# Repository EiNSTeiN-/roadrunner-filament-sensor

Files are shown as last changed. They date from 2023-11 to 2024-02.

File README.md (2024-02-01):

# Roadrunner: a high resolution filament motion sensor

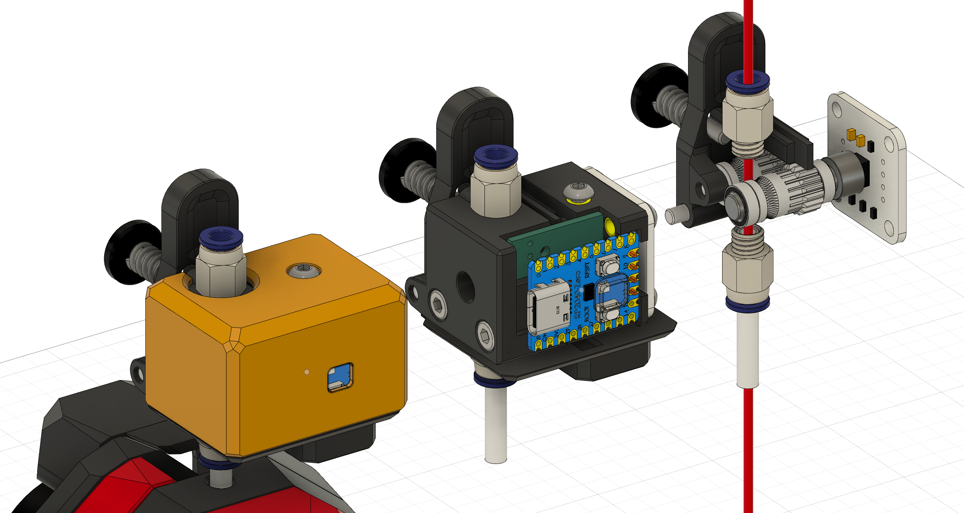
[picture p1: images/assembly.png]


### Features

* **High resolution** sub-millimeter motion detection
* **Low cost** at approx. ~12$ USD for parts on Aliexpress
* **Detect direction** (extruding or reversing) unlike pulse-based motion sensors
* Detect changes of **0.7 degree** or 0.04mm based on a 24mm rotation distance
* **Neopixel status indicator** for filament removed, filament inserted, filament moving
* **Small and light** at half the size of some commercial products
* **Helps determine runout reason** between filament runout, filament jams, or partial under-extrusion
* **2-wire communication** with mcu, over UART or I2C (suits most boards)
* **Calibrates max flow** with helpful gcode command.

Most 3D printer motion sensors are bulky, slow to trigger, prone to false positives, and have a high detection distance meaning a large amount material is extruded before actually detecting a runout, leading to poor layer adhesion and failed prints after a runout.

The Roadrunner motion sensor is based on a magnetic rotary encoder which can detect sub-millimeter movement in the filament for accurate extrusion length measurement, in addition to an IR sensor which can instantly detect filament runout. With the combination of both sensors and a dedicated RP2040-Zero board for collecting data, the Roadrunner can detect which type of issue is affecting a print, between simply reaching the end of a spool, the filament no longer moving, or the filament moving but at a lower than expected rate of extrusion.

By leveraging the higher precision of the sensor, it's possible to determine the length, speed and volumetric flow that are expected and compare them to the actual measured values in real time which gives us a reasonable approximation of _how much_ the filament is being under-extruded by. A simple to use `CALIBRATE_MAX_FLOW` command is provided to perform free-air extrusion tests and automatically benchmark the maximum volumetric flow of any temperature/nozzle/material combination.

### Build guide

This is an open-source project, so you can build your own!

See the [bill of material](manual/BOM.md) and the [assembly manual](manual/ASSEMBLY.md).

### Klipper installation

Clone the repository and create a symlink to the sensor code:

```
cd ~
git clone --depth 1 --single-branch https://github.com/EiNSTeiN-/roadrunner-filament-sensor.git
~/roadrunner-filament-sensor/install.sh
```

Restart klipper for the new sensor type to be recognized:
```
sudo service klipper restart
```

To get automatic updates within moonraker, add the following block at the end of `moonraker.conf`:
```ini
[update_manager roadrunner-filament-sensor]
type: git_repo
path: ~/roadrunner-filament-sensor
origin: https://github.com/EiNSTeiN-/roadrunner-filament-sensor.git
install_script: install.sh
primary_branch: main
managed_services: klipper
```

### Configuration

Add the following configuration to your `printer.cfg`:

```
[high_resolution_filament_sensor roadrunner]
extruder: extruder
#  The extruder to which this sensor is attached
uart_rx_pin: P0.0
uart_tx_pin: P0.1
#  TX and RX pins for UART communication, leave out if i2c or USB serial is used (see below).
#i2c_address: 64
#  The address of the sensor on the I2C bus, the default is 64 (0x40). Only
#  change this if you attach more than one sensor on the same I2C bus.
#i2c_mcu: mcu
#  The mcu on which the sensor is connected.
#i2c_bus: i2c1
#  The I2C bus to which the sensor is connected on the mcu.
#serial: /dev/serial/by-id/usb-Raspberry_Pi_Pico_E66130100F655734-if00
#  The serial port over which the sensor is connected. Find with `ls -alh /dev/serial/by-id`.
pause_on_runout: False
#  Whether or not to pause the print automatically when a runout
#  condition is triggered.
runout_gcode: RESPOND TYPE=command MSG='Filament runout detected'
#  The gcode to execute when a runout condition is detected.
invert_direction: False
# If the measured distance/speed values are negative, change this to True.
rotation_distance: 23.4
# The length of filament which corresponds to a full 360 degree rotation
# of the magnet over the rotary encoder. A good starting point is the
# circumference of the BMG gears in the sensor.
underextrusion_max_rate: 0.5
# What rate of underextrusion can be tolerated, as a value between 0.0 and 1.0.
# The rate is calculated by comparing the extruder position to the measured
# filament length over a certain period. A rate of 0.0 means the measured
# filament motion matches the expected extrusion distance over the period.
# A rate of 1.0 means no filament motion was detected at all when some motion
# was expected for the extruder.
underextrusion_period: 5
# How long should the underextrusion rate stay above the max rate before
# a runout is triggered.
hysteresis_bits: 3
# How many bits to ignore from the magnetic rotary encoder's angle data.
# This setting determines the minimum detectable change in position
# for the sensor. Configuring this too low can result in flapping between
# two adjacent positions even when the filament is not moving.
```

Two virtual pins are created for each sensor, which can be used to configure a [`filament_motion_sensor`](https://www.klipper3d.org/Config_Reference.html#filament_motion_sensor) or a [`filament_switch_sensor`](https://www.klipper3d.org/Config_Reference.html#filament_switch_sensor). This is mainly for convenience of use with user interfaces like mainsail/fluid. The virtual motion sensor will be triggered as soon as the sensor moves by the minimum detectable distance. The switch sensor will trigger when the IR sensor detects the filament is present. Both objects will work independently of the runout detection algorithm implemented in `high_resolution_filament_sensor` which considers additional factors such as underextrusion.

An example configuration would look like:

```
[filament_motion_sensor roadrunner_motion]
detection_length: 2
extruder: extruder
switch_pin: virtual_motion_sensor:roadrunner
pause_on_runout: False
runout_gcode: RESPOND TYPE=command MSG='Filament motion sensor detected a runout'
event_delay: 0.1

[filament_switch_sensor roadrunner_switch]
switch_pin: virtual_switch_sensor:roadrunner
pause_on_runout: False
runout_gcode: RESPOND TYPE=command MSG='Filament switch sensor detected filament is no longer present'
event_delay: 0.1
```

### Usage

##### Calibration cheat sheet

Here's an example of a complete calibration workflow:

```
# Disable a few things for these tests
SET_PRESSURE_ADVANCE EXTRUDER=extruder ADVANCE=0
SET_Z_THERMAL_ADJUST TEMP_COEFF=0 ENABLE=0

# Optionally home the printer and move to a safe Z
G32
G0 Z100

# Check your sensor info
QUERY_FILAMENT_SENSOR SENSOR=roadrunner

# Find rotation_distance value, don't forget to save it in the sensor config & restart.
CALIBRATE_FILAMENT_SENSOR_ROTATION_DISTANCE SENSOR=roadrunner TEMP=250 LENGTH=30 SPEED=30 COUNT=10

# Find max flow for this extruder, save the graph of collected data for future reference (THIS WILL TAKE A WHILE)
CALIBRATE_MAX_FLOW SENSOR=roadrunner TEMP=250 START=1 STOP=40 SAVE_GRAPH=1

# Measure a G1 command at a high speed (e.g. 11.5mm/s = 690mm/m).
# Use a value that will produce a flow in the non-linear part of the curve in the previous graph.
FILAMENT_SENSOR_MEASURE SENSOR=roadrunner TEMP=250 SPEED=690 LENGTH=100 SAVE_GRAPH=1

# Enable nonlinear extrusion with coefficients suggested by `CALIBRATE_MAX_FLOW`
ENABLE_NONLINEAR_EXTRUSION SENSOR=roadrunner ENABLE=1 COEFFICIENTS=-0.1106867,1.1197162,-0.0347608,0.0028625

# Take same measurement again, the measured length and speed should show little deviation.
FILAMENT_SENSOR_MEASURE SENSOR=roadrunner TEMP=250 SPEED=690 LENGTH=100 SAVE_GRAPH=1

# Now check the result of the extrusion compensation by generating a new graph (THIS WILL TAKE A WHILE)
CALIBRATE_MAX_FLOW SENSOR=roadrunner TEMP=250 START=1 STOP=40 STEP=2 COUNT=2 SAVE_GRAPH=1
```

##### Calibrate the sensor's rotation distance:

The first thing to do is to calibrate the `rotation_distance` for the sensor itself. This is done
with `CALIBRATE_FILAMENT_SENSOR_ROTATION_DISTANCE`:

```
CALIBRATE_FILAMENT_SENSOR_ROTATION_DISTANCE SENSOR=roadrunner TEMP=250 LENGTH=30 SPEED=60 COUNT=10
```

* `TEMP`: The temperature to heat up the extruder heater at. Default is 200.
* `LENGTH`: The length of filament to retract. Default is 25.
* `SPEED`: The extrusion speed, in rotation per minute (e.g. 300 means 5mm/s). Default is 30 (0.50mm/s).
* `COUNT`: How many times to perform the test. Default is 10.

This macro will heat up the extruder heater to the specified temperature, retract the filament multiple times,
and calculate some stats. The measurement is done while retracting the filament to avoid introducing an error
due to the back-pressure in the nozzle. Make sure a length of filament at least `LENGTH` mm long can
be retracted while still being gripped by the extruder gears. For best results, perform this test at low
speed over a distance long enough for the sensor's gears can do one full rotation.

After the distance measurements are taken, they are sorted by frequency and the measurement with the highest frequency is used to calculate a new `rotation_distance`. For example, if 8/10 measurements read 25.62mm when 25mm was expected, the `rotation_distance`
was too high and a new value is automatically suggested. After saving the new `rotation_distance` in your sensor configuration, repeating the test with the same macro parameters should measure the correct distance. The deviation between measurements is reported relative to the minimum detectable change in position, a small deviation indicates repeatable measurements. While the sensor is
high precision, its accuracy and repeatability over multiple readings can be affected by real world factors such as
springiness in the PTFE tube, the attachement of the sensor to the body of the extruder, etc.

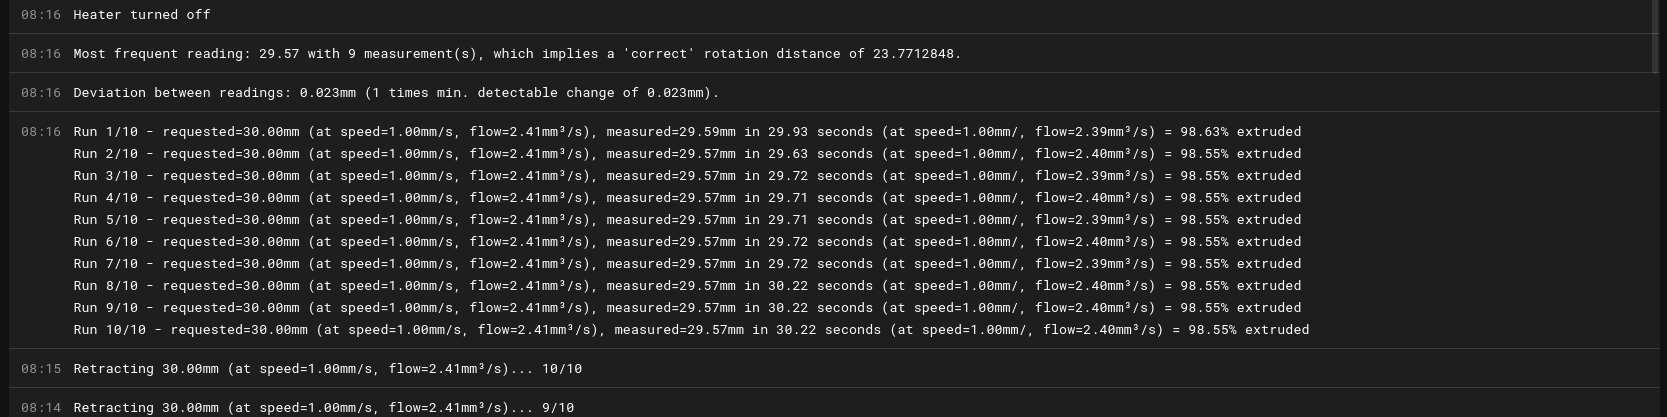
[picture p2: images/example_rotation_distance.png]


##### Measure a G1 command

Extrude some filament using a G1 command, and print the result as measured by the sensor.

```
FILAMENT_SENSOR_MEASURE SENSOR=roadrunner TEMP=250 LENGTH=10 SPEED=120 COUNT=1
```

* `TEMP`: The temperature to heat up the extruder heater at. Default is 200.
* `LENGTH`: The length of filament to retract. Default is 10.
* `SPEED`: The extrusion speed, in rotation per minute (e.g. 300 means 5mm/s). Default is 120 (2mm/s).
* `COUNT`: How many times to perform the test. Default is 1.
* With the `SAVE_GRAPH=1` parameter, a graph of all measurements is saved to klipper's current working directory (usually `~/klipper/`).

The macro will run one or more G1 command until the desired length of filament is extruded. The macro will print stats for each move, as measured by the sensor.

Optionally if a graph is saved, the output will look like this:

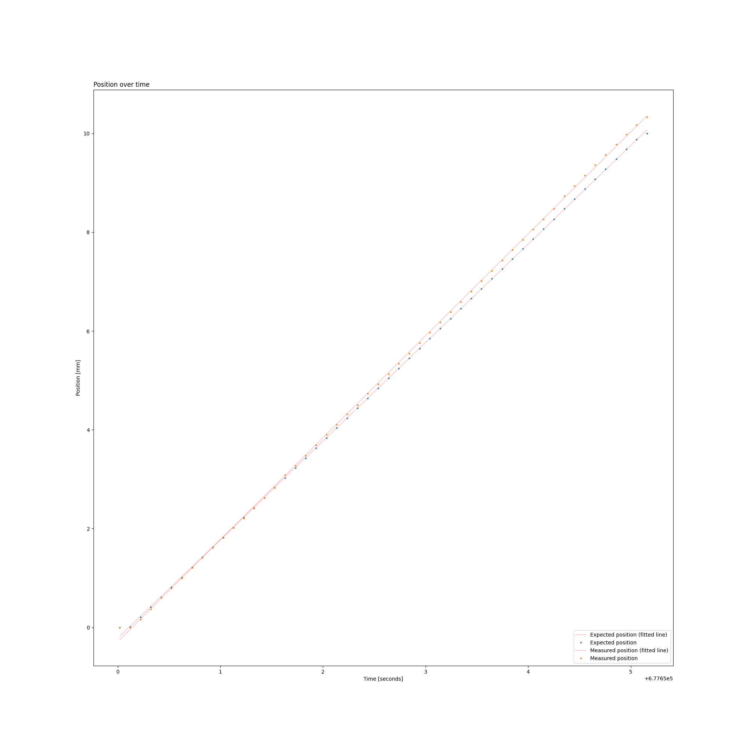
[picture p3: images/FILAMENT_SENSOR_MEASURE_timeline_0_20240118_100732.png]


##### Max flow calibration

The goal of this macro is to help determine the maximum volumetric flow for a given combination of filament, nozzle and temperature. Before starting, make sure your extruder's `filament_diameter` is correct, as well as the filament sensor's `rotation_distance`. For best results, the `STOP` value should be above or near the top of your extruder's expected maximum volumetric flow rate.

```
CALIBRATE_MAX_FLOW SENSOR=roadrunner TEMP=250 START=1 STOP=50 SAVE_GRAPH=1
```

* `TEMP`: The temperature to heat up the extruder heater at. Default is 200.
* `DURATION`: How long to extrude for during each test, used to determine the extrusion length (length = speed * duration). Default is 10 seconds.
* `START`: The minimum volumetric flow to test. Default is 5.
* `STOP`: The maximum volumetric flow to test. Default is 25.
* `STEP`: The amount by which to increment the volumetric flow between each test. Default is 1.
* `COUNT`: How many times to perform the test for each volumetric flow value. Default is 5.
* `MAX_SPEED_DEVIATION`: The percentage of deviation between the expected and the measured speed that will be considered acceptable. Used for recommending a maximum volumetric flow. Default is 0.05 (5%).
* With the `SAVE_GRAPH=1` parameter, a graph of all measurements is saved to klipper's current working directory (usually `~/klipper/`).

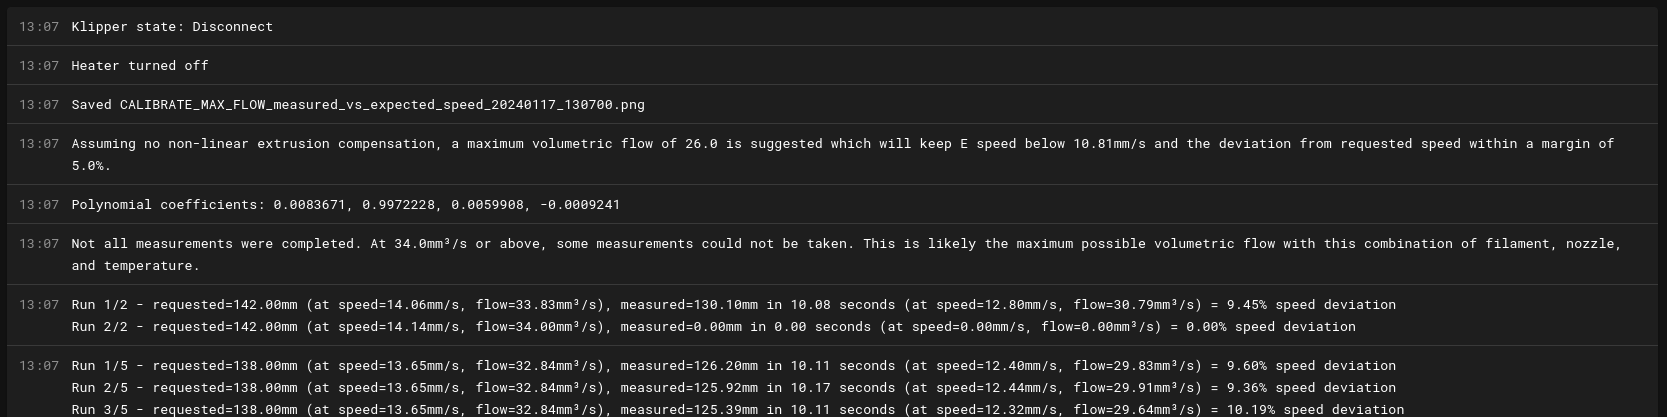
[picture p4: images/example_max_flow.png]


This macro will warn when a given volumetric flow was so high that not all measurements could be taken at this rate. This often corresponds to the physical limit of the extruder, where the back-pressure is so high that the extruder cannot keep up and eats into the filament.

After the measurements are taken, this macro will look for a range of speeds where the deviation between the expected and measured speeds is below `MAX_SPEED_DEVIATION` percent. At higher speeds, the back-pressure in the nozzle will cause under-extrusion, this can be identified visually in the data graph (use `SAVE_GRAPH=1`) as a part of the curve where the exected and measured speeds start deviating sharply. A polynomial curve is fitted to the relationship between the expected vs measured speeds, which can be used to compensate for the under-extrusion at higher speeds.

Optionally if a graph is saved, the output will look like this:

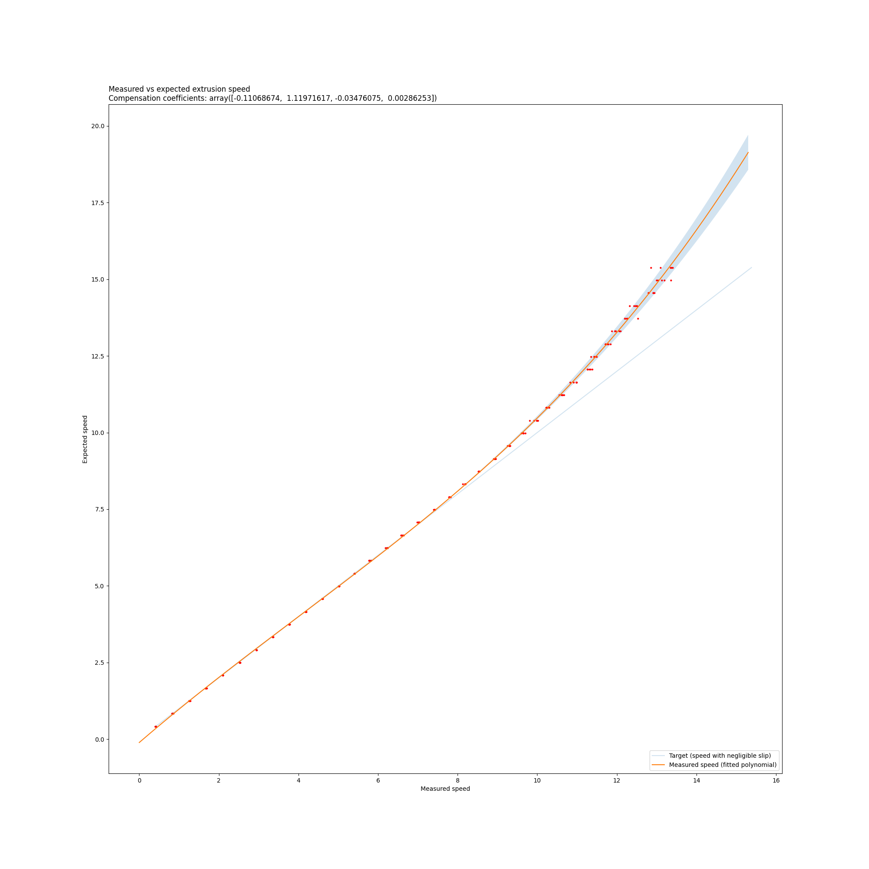
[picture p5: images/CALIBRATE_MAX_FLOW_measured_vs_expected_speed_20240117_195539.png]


##### Enable non-linear extrusion compensation (EXPERIMENTAL)

A `[non_linear_extrusion]` config section must be added for this command to work with a given extruder:
```
[non_linear_extrusion t0]
extruder: extruder
# Name of the extruder for which nonlinear extrusion compensation can optionally
# be enabled.
```

When non-linear extrusion compensation is enabled, the increase in pressure in the extruder will be compensated by increasing the requested speed of G1 commands. This applies to both extrude-only moves as well as regular printing moves. The compensation is only applied when using relative coordinates and only when a positive E distance is specified since retraction moves are not affected by pressure in the nozzle.

```
ENABLE_NONLINEAR_EXTRUSION EXTRUDER=extruder ENABLE=1 COEFFICIENTS=-0.1106867,1.1197162,-0.0347608,0.0028625
```

* `ENABLE`: 1 to enable, 0 to disable
* `COEFFICIENTS`: A list of comma-separated polynomial coefficients.

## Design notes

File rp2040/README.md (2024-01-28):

### Dependencies

```
sudo apt install cmake gcc-arm-none-eabi libnewlib-arm-none-eabi libstdc++-arm-none-eabi-newlib
```

### Configuring

Some neopixels have RGB color ordering while others have GRB. When the filament is inserted the LED should ligth green, if it is RED then you should use the GRB ordering. Uncomment the following line in `neopixel.h` and re-run `make` to build the firmware.

```
#define GRB_LED_ORDER 1
```

### Building

```
git clone https://github.com/EiNSTeiN-/roadrunner-filament-sensor.git
cd roadrunner-filament-sensor
git submodule update --init --recursive
cd rp2040
mkdir build
cd build
cmake ..
make
```

You'll find multiple `.uf2` files in the `roadrunner-filament-sensor/rp2040/build` directory. The name contains `uart`, `i2c` or `usbserial` for the communication mode between mcu and sensor, and `rgb` vs `grb` for the neopixel type.

### Flashing

1. Connect RP2040-Zero to computer via USB
2. Press `BOOT` and `RESET` at the same time
3. Release `RESET` and 1 second later release `BOOT`
4. A drive named `RPI-RP2` will appear
5. Copy newly built `.uf2` file to the drive to flash the new firmware.

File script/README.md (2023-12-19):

### Dependencies

This step is only needed once:

```
python3 -m venv ./venv
source ./venv/bin/activate
pip install -r requirements.txt
```

### Usage

Make sure the venv is activated before running the commands below:
```
source ./venv/bin/activate
```

See help for all command line options:

```
python3 main.py -h
```

##### Stream live data from printer

```
python3 main.py --http --live mainsailos.local
```

##### Save live data from printer to a file

```
python3 main.py --live mainsailos.local -f data.json
```

`--http` and `-f` can be combined to stream and save to a file at the same time.

##### Replay saved data from a file

```
python3 main.py --http --replay data.json
```

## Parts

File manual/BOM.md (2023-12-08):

# BOM

### Printed parts

Recommended settings:
* 0.2mm layer height
* 0.5mm (250%) layer width
* Cubic infill, 60%
* Supports enabled

| Part | Quantity | Notes |
|---|---|---|
| [a]_cover.stl | 1 | Print in accent color
| [c]_led_diffuser.stl | 1 | Print in clear material
| body_part_a.stl | 1 | Print in main color
| body_part_b.stl | 1 | Print in main color
| idler.stl | 1 | Print in main color
| magnet_holder.stl | 1 | Print in main color
| wire_cover.stl | 1 | Print in main color

### Electronics

Order the cheapest you can find of the following items:

| Qty. | Part | Est. Price | Description | Link |
|----|----|----|----|----|
| 1 | AS5600⁽¹⁾ | 1$ | Magnetic encoder breakout board, used for rotation detection | [aliexpress](https://vi.aliexpress.com/item/1005003080438185.html)
| 1 | MK3S IR Sensor⁽²⁾ | 5$ | IR sensor for filament presence detection | [aliexpress](https://vi.aliexpress.com/item/1005002551124258.html)
| 1 | Waveshare RP2040-Zero | 3$ | Order the board only without pre-soldered headers | [aliexpress](https://vi.aliexpress.com/item/1005004281549886.html)
| 1 | Wires | | Some lengths of wire to connect everything together (soldering required) | |
| 1 | JST-XH male 4-pin | | (Optional) Fits in the provided bottom cover | |

Notes:
1. The linked AS5600 breakout board comes with a 3mm diameter magnet. If you must purchase a magnet separately, make sure it has its poles oriented across its diameter, not across the thickness.
2. The IR sensor does not require any of the usual MK3S hardware although many kits on Aliexpress are sold with the extra hardware. Only a small 2mm self-tapping screw is needed to attach the PCB.

### Hardware

| Qty. | Part | Est. Price | Description | Link |
|----|----|----|----|----|
| 1 | BMG extuder kit⁽¹⁾ | 5$ | The kit should include the thumb screw assembly, drive gears, roller bearings, needle bearings, 3 x 20mm and 3 x 30mm shafts. | [aliexpress](https://vi.aliexpress.com/item/1005005443742333.html)
| 1 | M5 x 25mm rod⁽¹⁾ | 2$ | Order a longer length and cut up to size between 24 and 26mm | [aliexpress](https://vi.aliexpress.com/item/1005005041338002.html)
| 2 | M3 x 16mm SHCS | | Connects sensor body part A and B. Socket head screws recommended | |
| 6 | M3 x 6mm BHCS | | For AS5600, top and bottom covers. Button head screws required for clearance | |
| 1 | M3 x 10mm BHCS | | For bottom cover. | |
| 10 | M3 X D4.2 X L4.0 heatset inserts | | These are smaller than Voron standard inserts! | [aliexpress](https://vi.aliexpress.com/item/4000761483243.html) |
| 2 | PC4-M5 fitting | | To connect with PTFE tubes on top and bottom | [aliexpress](https://vi.aliexpress.com/item/1005005646446620.html) |

Notes:
1. It's possible to use the shaft of the large plastic gear that comes with the BMG extruder kit instead of purchasing a separate 5mm rod. Simply push out the plastic gear and grind down the theethed part of the shaft so that it fits properly in the 5mm bearings.

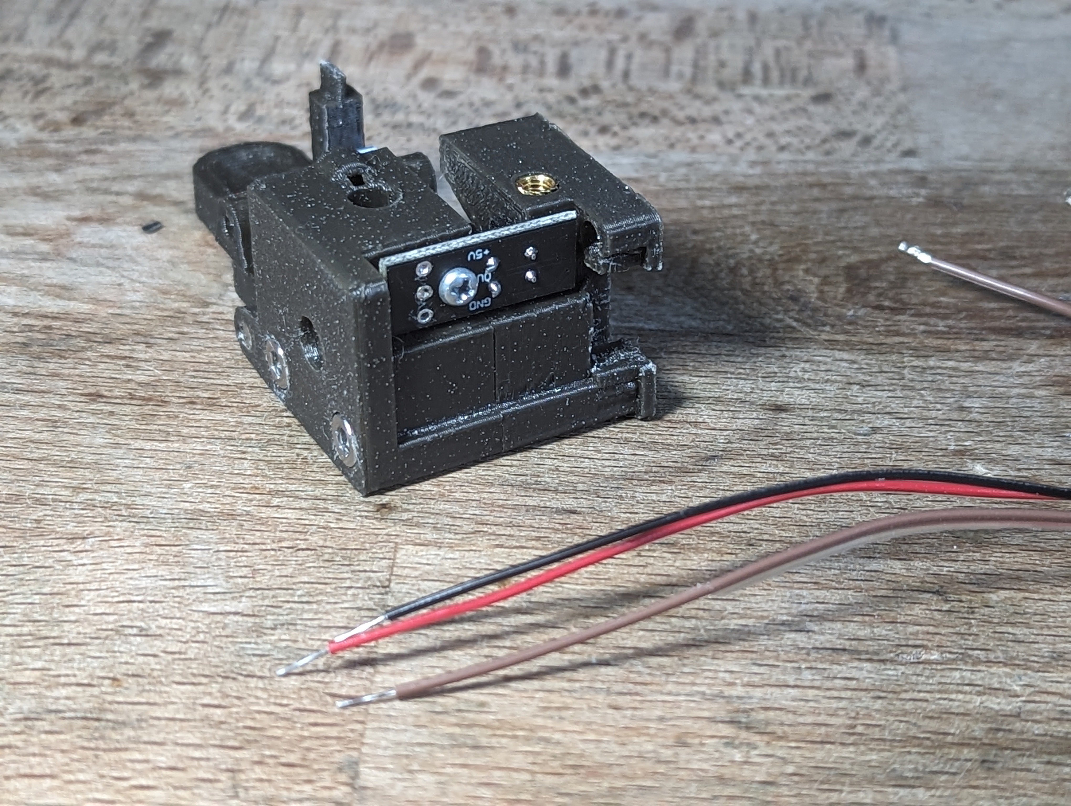
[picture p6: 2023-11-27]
images/manual/013_parts.jpg

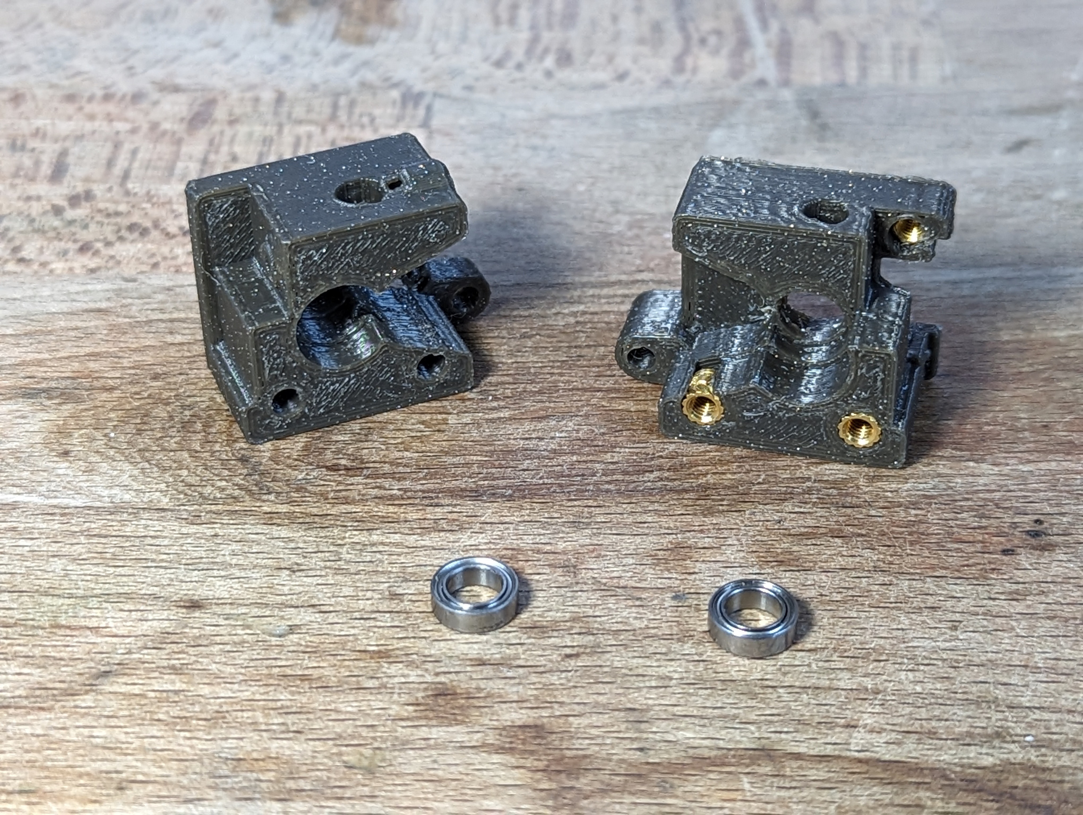
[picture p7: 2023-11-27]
images/manual/004_parts.jpg

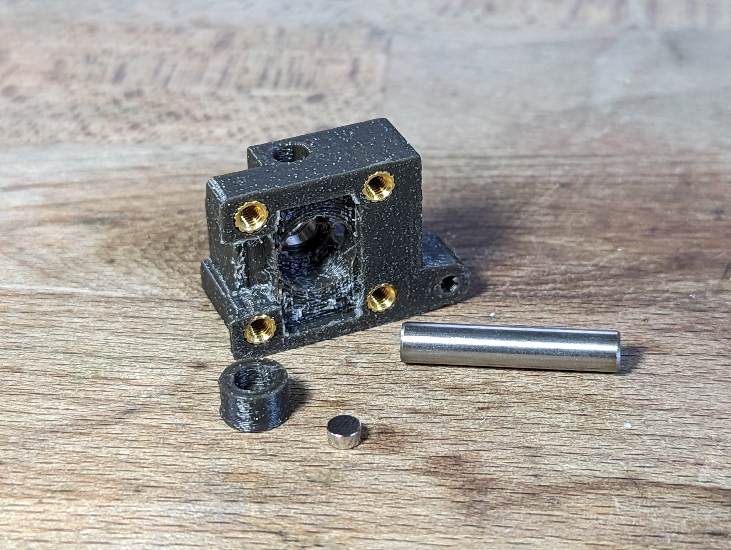
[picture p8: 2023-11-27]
images/manual/005_parts.jpg

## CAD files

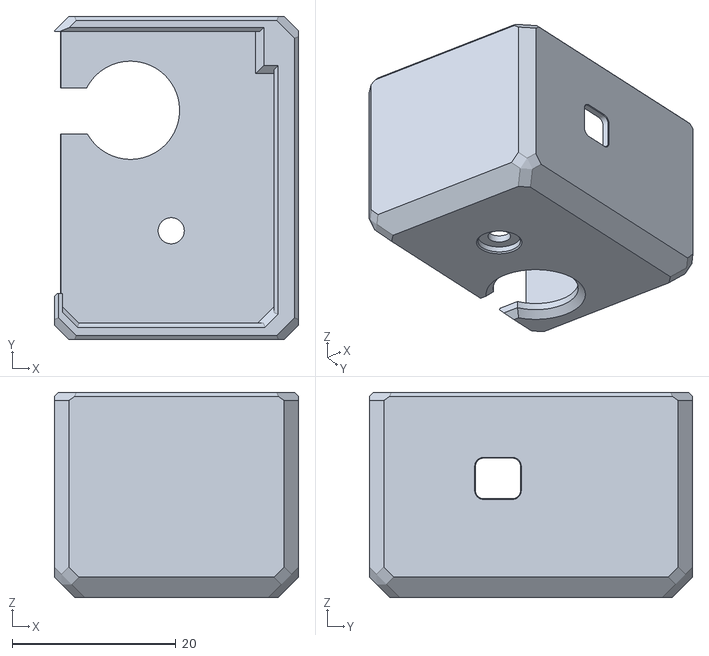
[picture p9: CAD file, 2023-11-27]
STLs/[a]_cover.stl
29.8 x 39.5 x 25.1

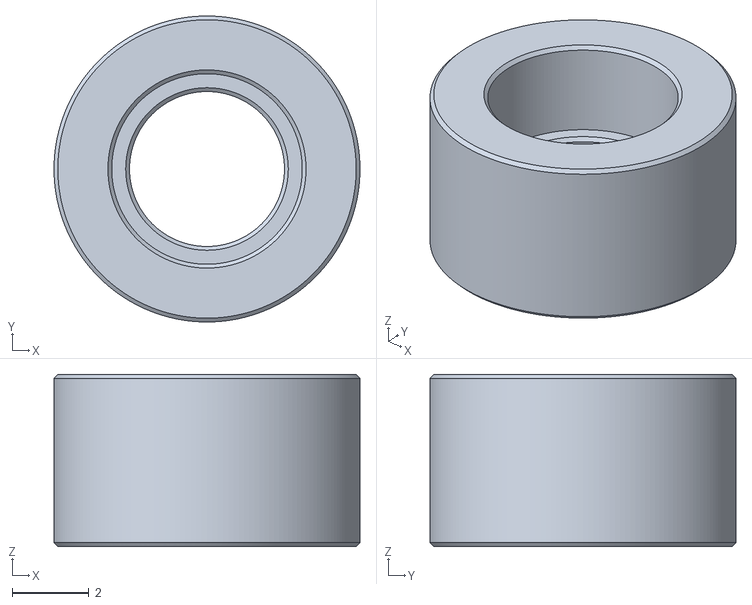
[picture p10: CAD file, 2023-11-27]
STLs/magnet_holder.stl
8.00 x 8.00 x 4.50

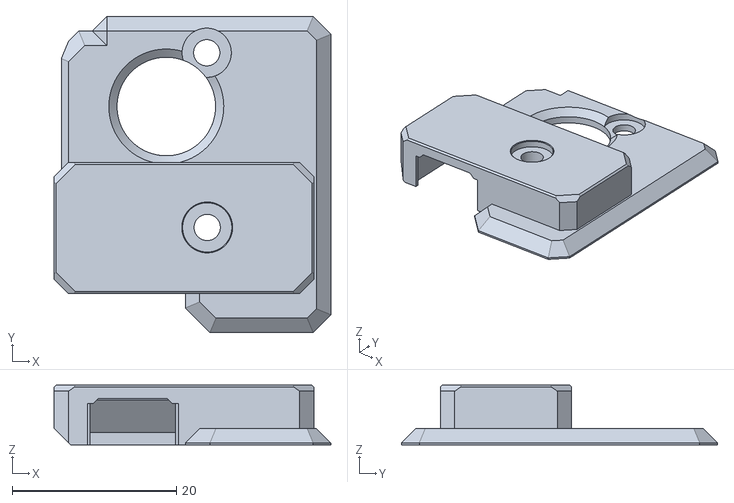
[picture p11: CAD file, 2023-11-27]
STLs/wire_cover.stl
33.7 x 38.5 x 7.30

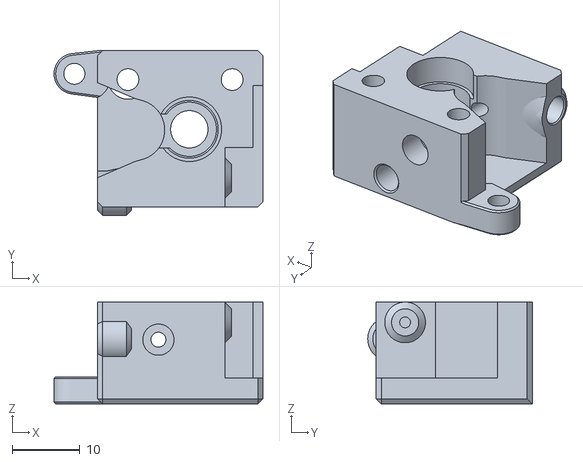
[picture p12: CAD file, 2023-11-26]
STLs/body_part_b.stl
30.8 x 24.2 x 15.0

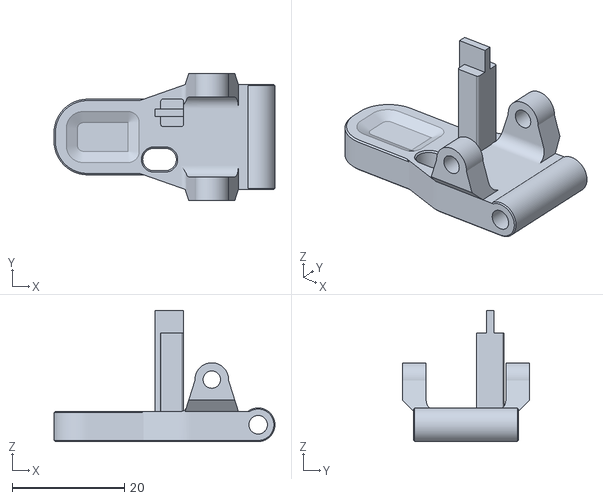
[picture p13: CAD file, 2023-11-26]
STLs/idler.stl
39.4 x 22.7 x 23.4

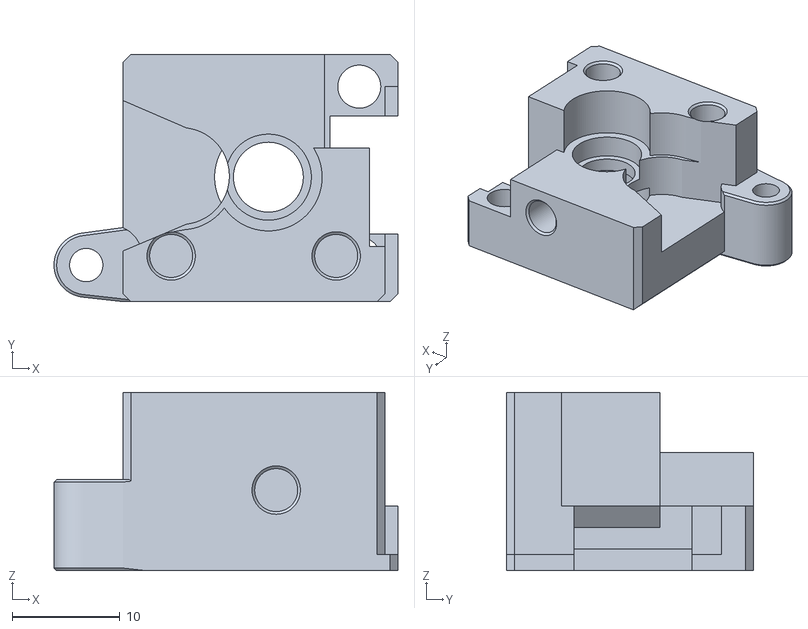
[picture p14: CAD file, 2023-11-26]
STLs/body_part_a.stl
32.0 x 23.0 x 16.6

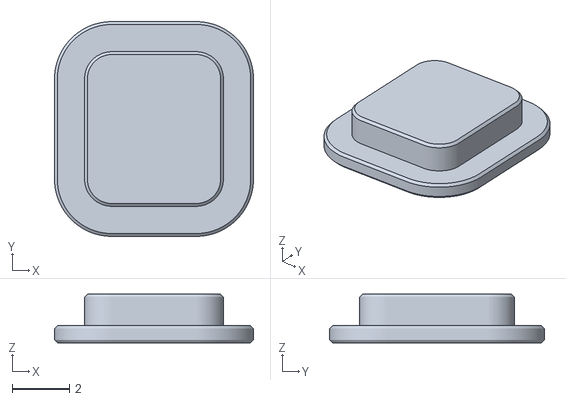
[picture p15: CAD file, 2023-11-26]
STLs/[c]_led_diffuser.stl
6.95 x 7.50 x 1.70

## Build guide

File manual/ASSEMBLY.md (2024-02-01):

# Roadrunner assembly manual

Gather all parts from the [bill of materials](BOM.md) before getting started.

### 1. Heat-set inserts

Add the heat-set inserts into `body_part_a.stl` and `body_part_b.stl`.

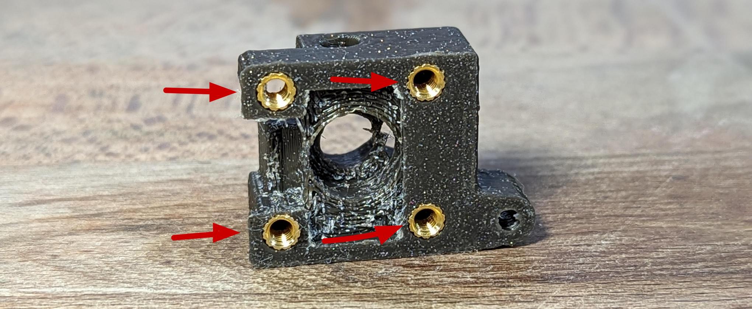
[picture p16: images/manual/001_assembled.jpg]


There is one last insert on the top not pictured below:

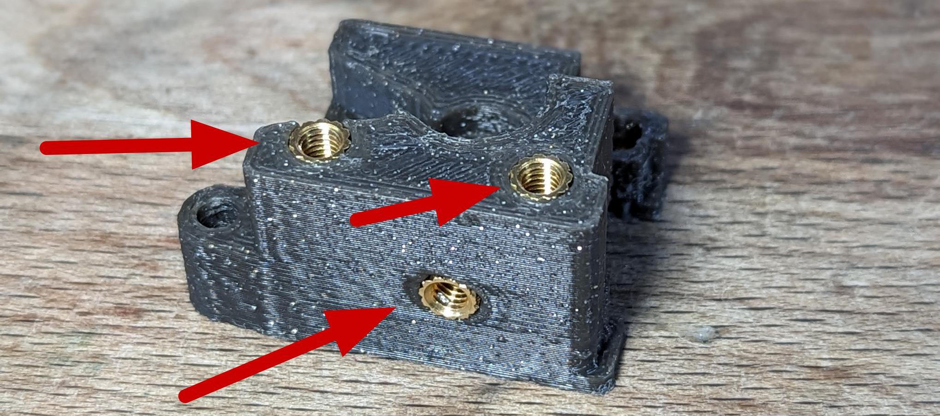
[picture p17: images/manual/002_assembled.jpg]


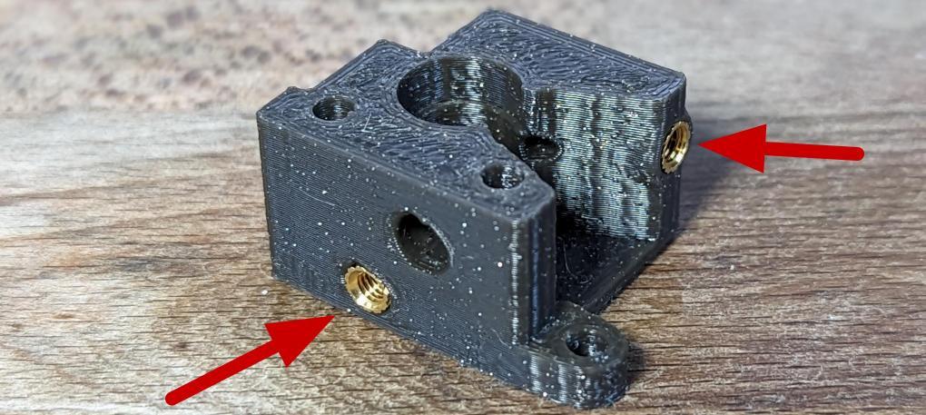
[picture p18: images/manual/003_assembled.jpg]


### 2. Idler assembly

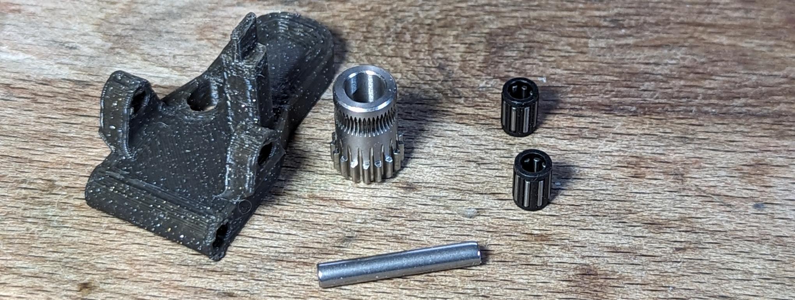
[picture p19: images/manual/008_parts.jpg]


Assemble `idler.stl` together with the idler gear, needle bearings, and the 3x20mm shaft.

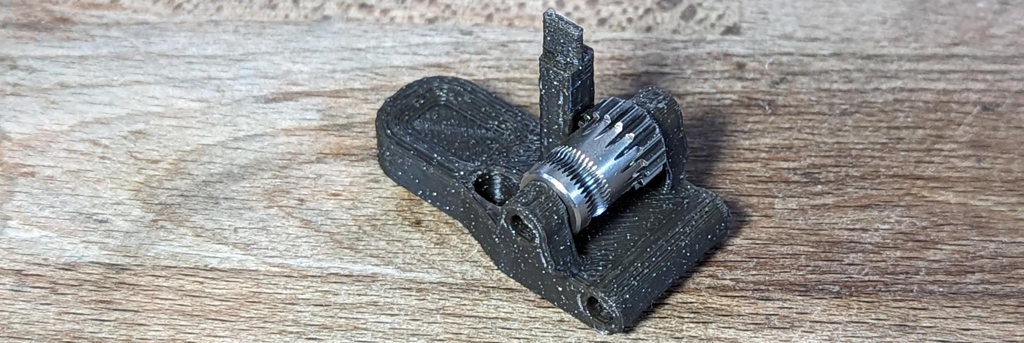
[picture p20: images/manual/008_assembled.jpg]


### 3. Main body assembly

Add the 5mm bearings into `body_part_a.stl` and `body_part_b.stl`.

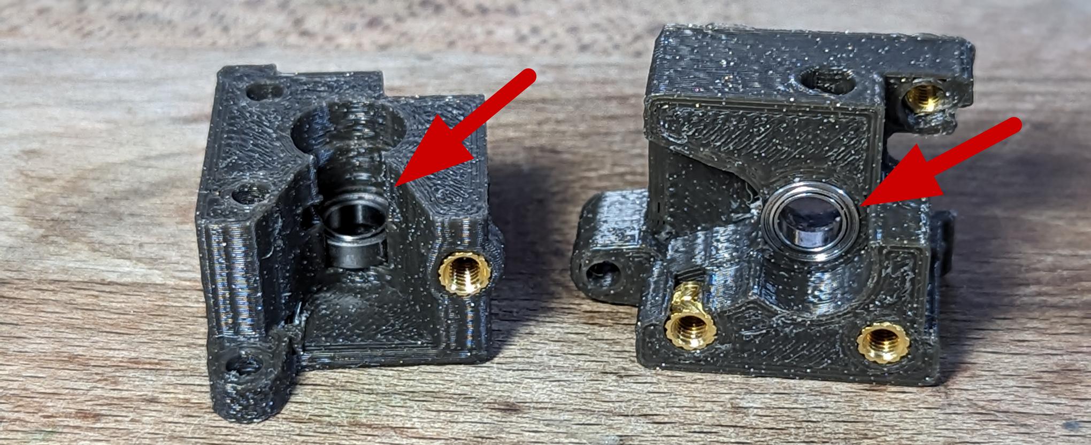
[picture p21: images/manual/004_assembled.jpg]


Assemble the 5mm shaft, 3x2 magnet and magnet holder parts.

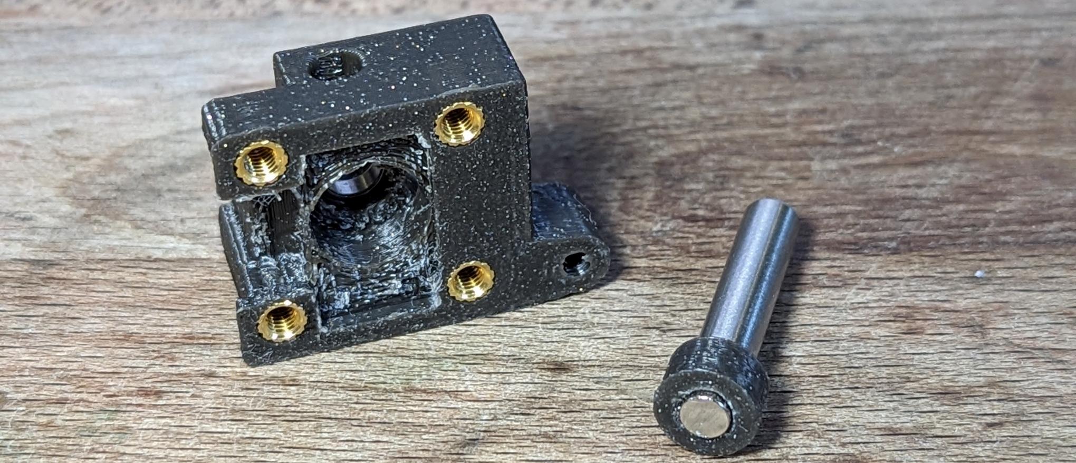
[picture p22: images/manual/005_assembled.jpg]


Fit the 5mm shaft into the bearing before adding the AS5600 board.

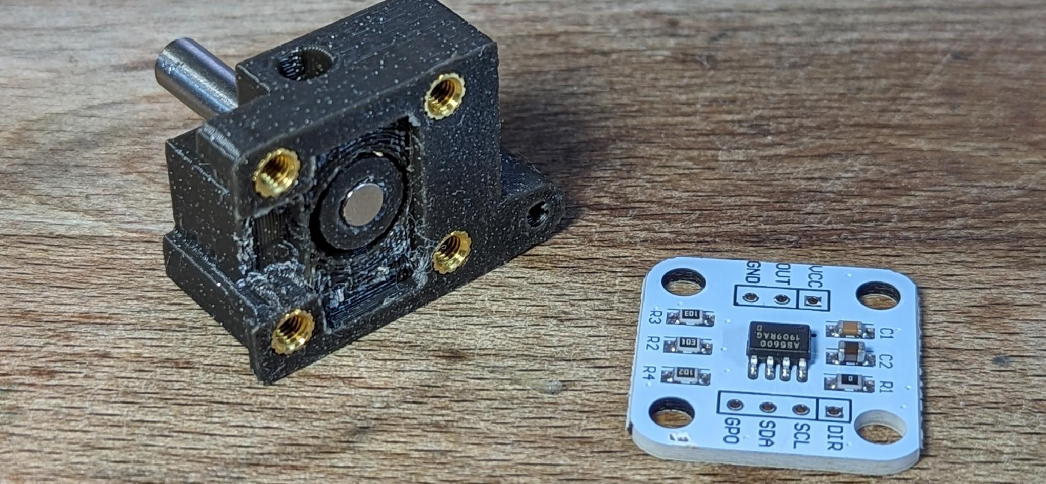
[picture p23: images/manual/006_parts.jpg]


Tighten the AS5600 board using M3 x 6mm BHCS screws, the 4-pin header should be aligned with the opening on the left. Make sure the 5mm shaft can spin freely once the screws are tight.

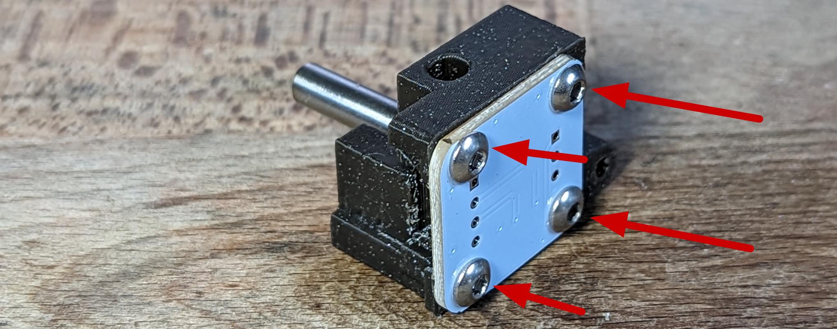
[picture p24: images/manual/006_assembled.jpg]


Add the drive gear to the 5mm shaft, take care to tighten the setscrew (with loctite). Add the 3x30mm shaft as well.

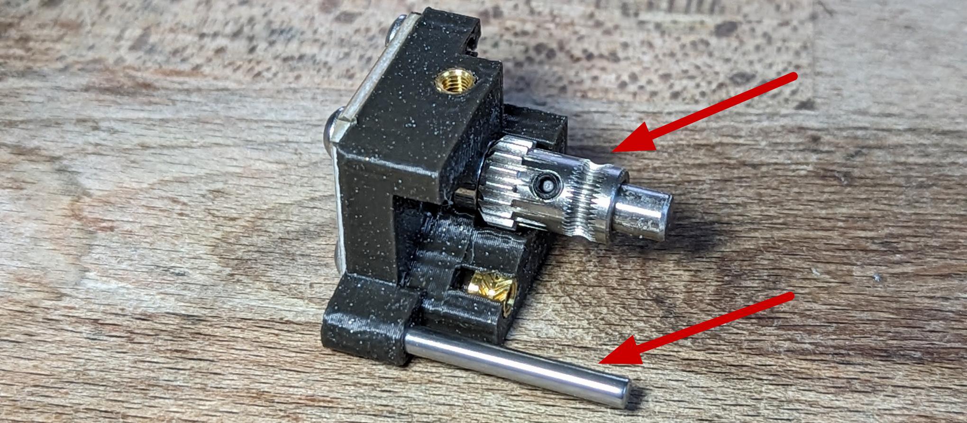
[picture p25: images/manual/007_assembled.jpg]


Complete the main body assembly by sliding the idler onto the 3mm shaft, screw the body A and B parts together using two M3 x 16mm SHCS.

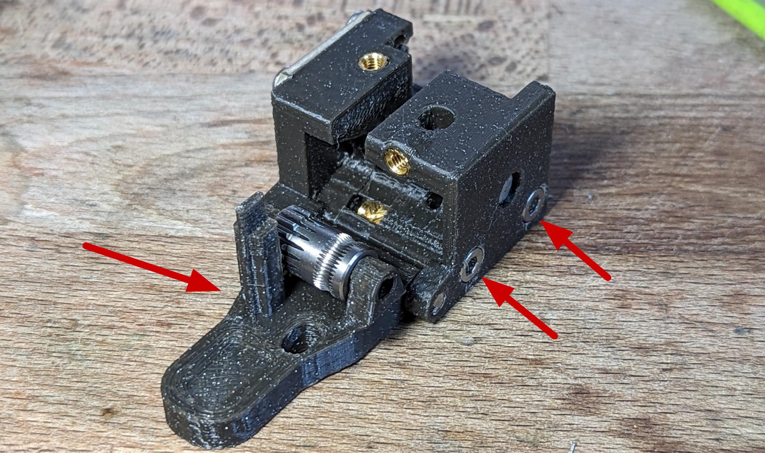
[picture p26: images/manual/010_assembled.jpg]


### 4. Electronics

The next step is to solder the electronics as shown here:

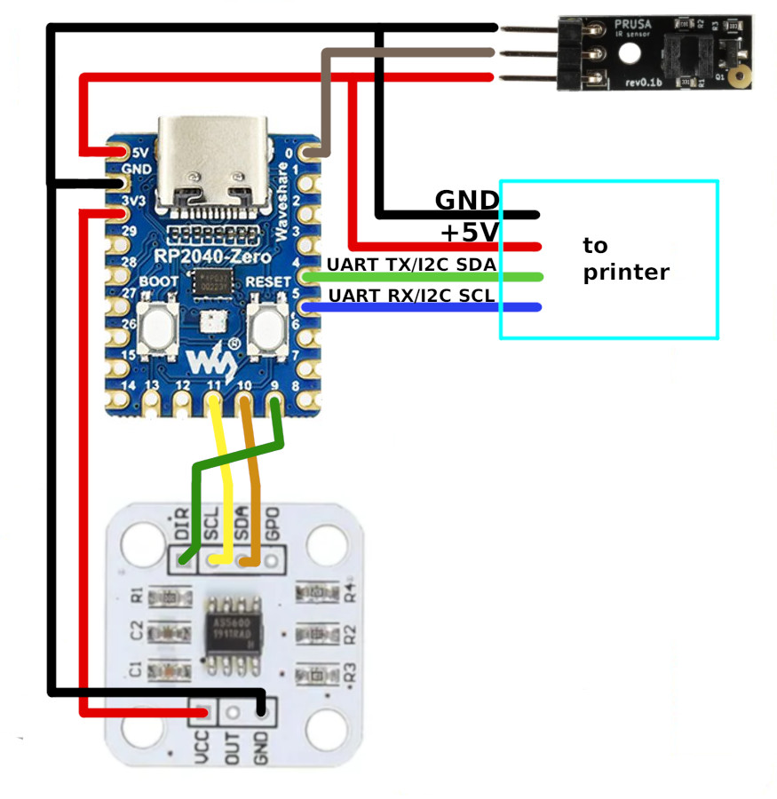
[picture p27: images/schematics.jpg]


Prepare the IR sensor by removing the 3-pin 0.1" header from the board.

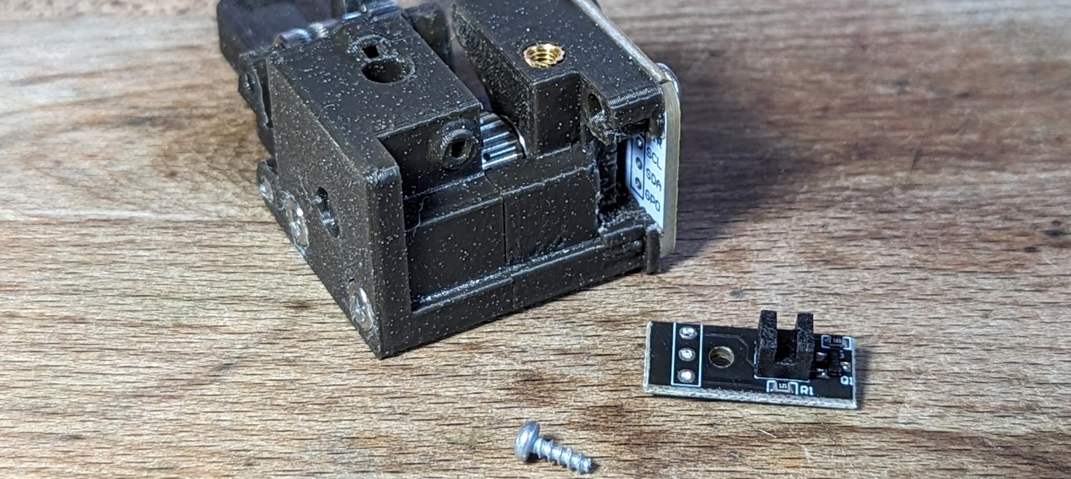
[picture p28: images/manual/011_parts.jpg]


Add the 2mm self-tapping screw and make sure the IR sensor lines up with the idler arm.

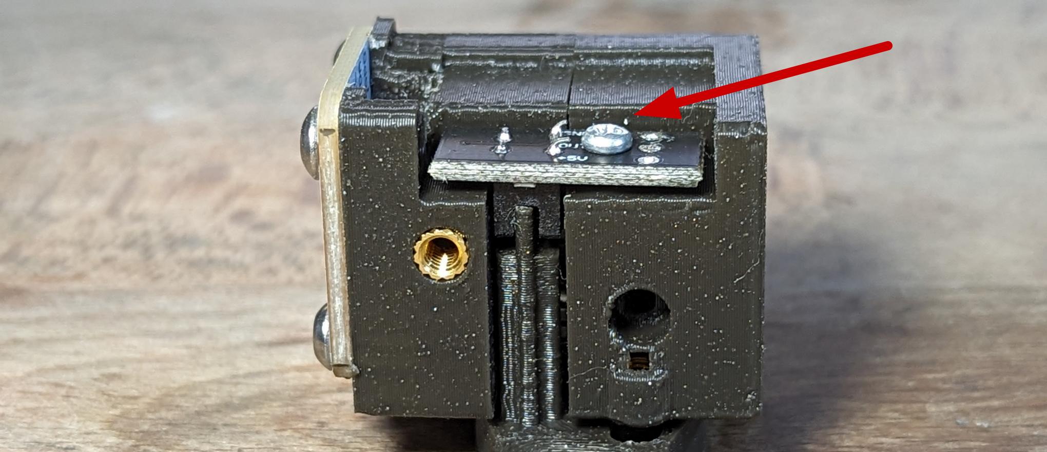
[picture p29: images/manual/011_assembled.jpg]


Prepare the RP2040-Zero and a 4-pin segment of 90-degree 0.1" header. The middle 2 pins should be removed since they are not connected straight between the two boards (we will solder them in reverse later).

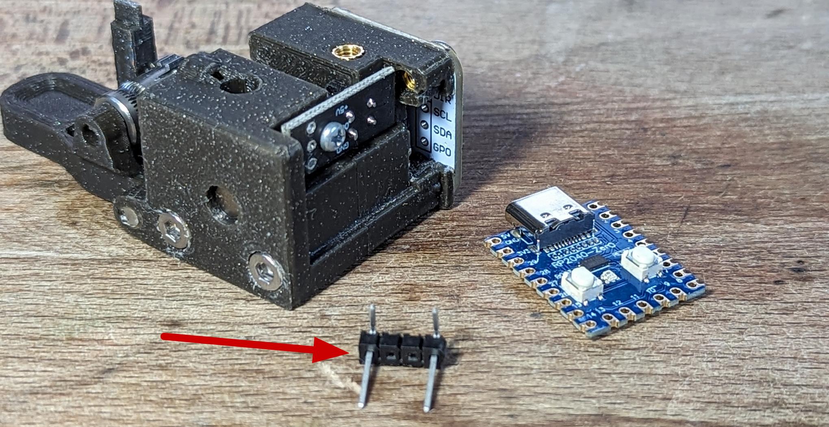
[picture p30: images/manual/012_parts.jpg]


Line up the 90-degree header with both boards and solder in place. Pay attention to solder on pins 9 and 12 (it's easy to be off-by-one and solder on the wrong pins).

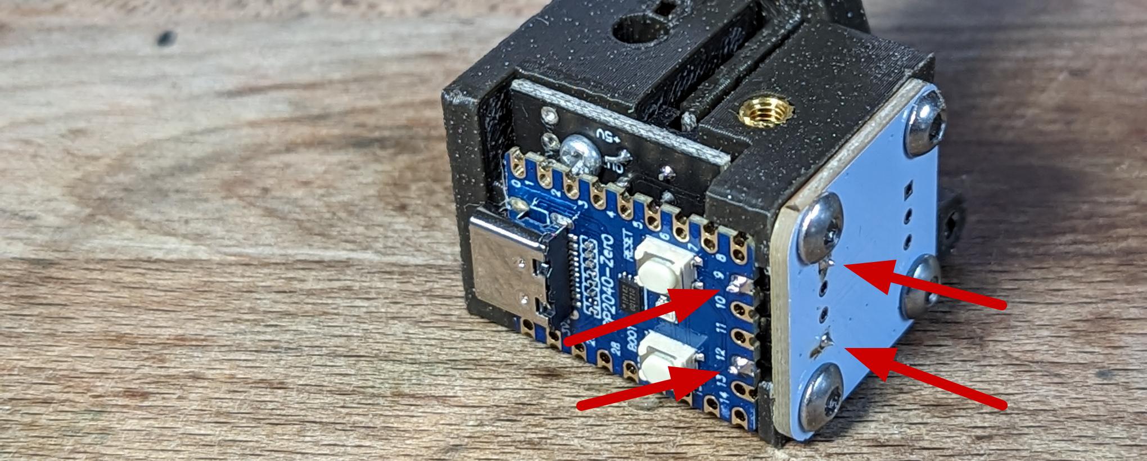
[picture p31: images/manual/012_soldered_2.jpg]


You should be able to remove both circuit boards together at this point. The middle two pins on the connector are still unsoldered, this is normal.

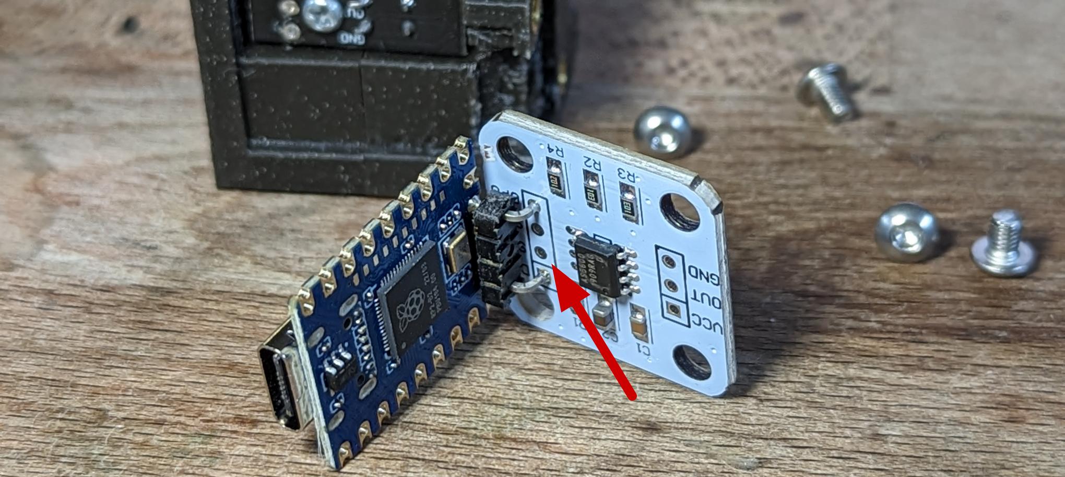
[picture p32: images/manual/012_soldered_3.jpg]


With the RP2040 set aside, solder some thin wires to the IR sensor board.

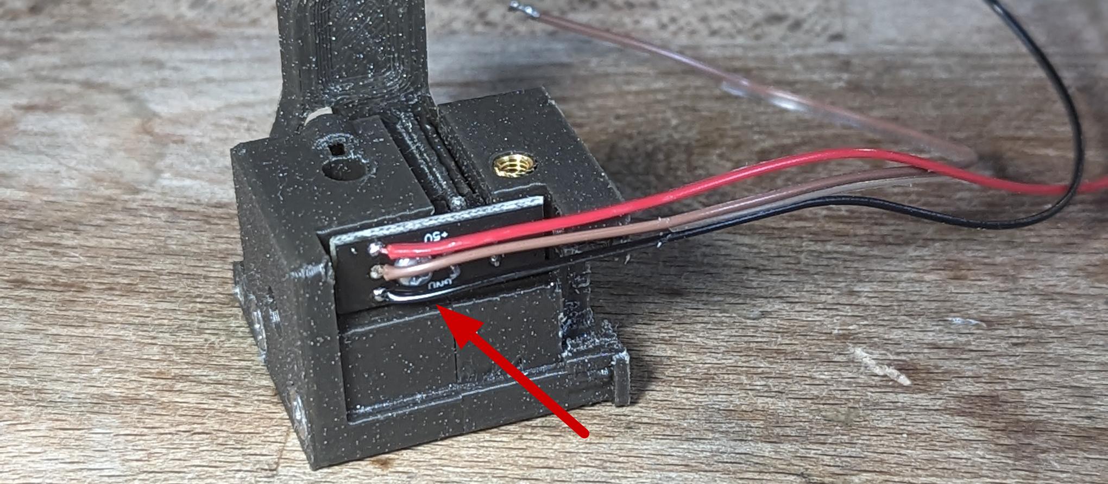
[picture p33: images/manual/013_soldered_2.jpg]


Add the RP2040 and AS5600 boards back in place, and cut the IR sensor wires to length.

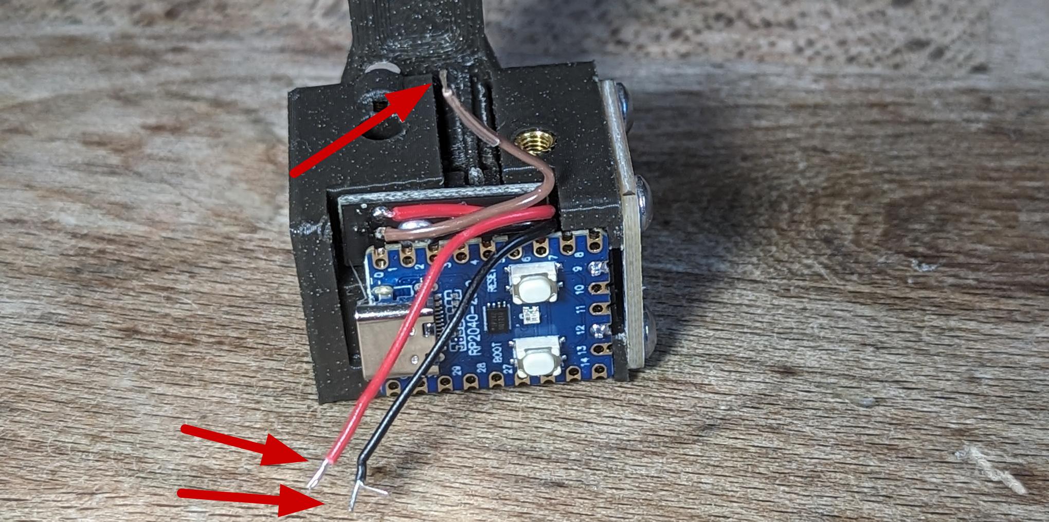
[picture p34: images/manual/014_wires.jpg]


The red (5V) and black (GND) wires should reach the bottom edge of the PCB, and the brown (middle) wire should reach the GP0 pin. There is a pocket between the two boards for the extra wire length to fit in.

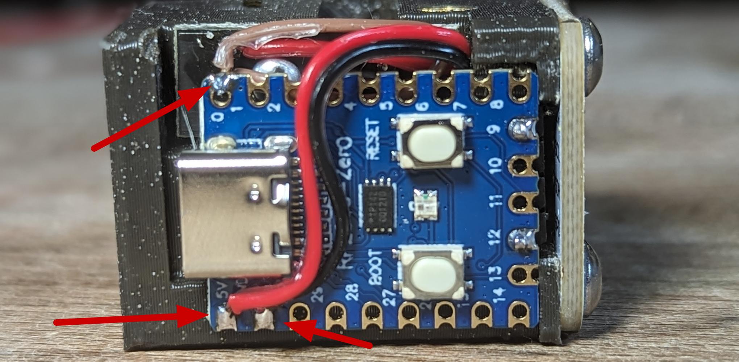
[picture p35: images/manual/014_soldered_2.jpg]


Add two wires between the RP2040 pins GP10/GP11 and the AS5600 pins SDA/SCL. Note that the I2C pin order on the two boards are reversed so the wires should cross each other!

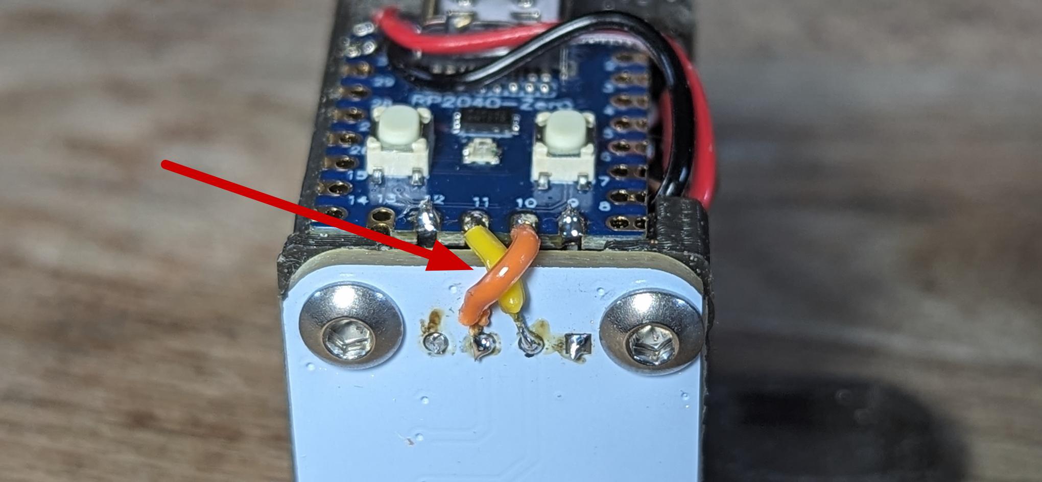
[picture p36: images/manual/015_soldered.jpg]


Solder the VCC and GND pads on the AS5600 board to the 3V3 and GND pads on the RP2040. The AS5600 board can be powered by 5V only if the 0Ω resistance (R1) is removed!

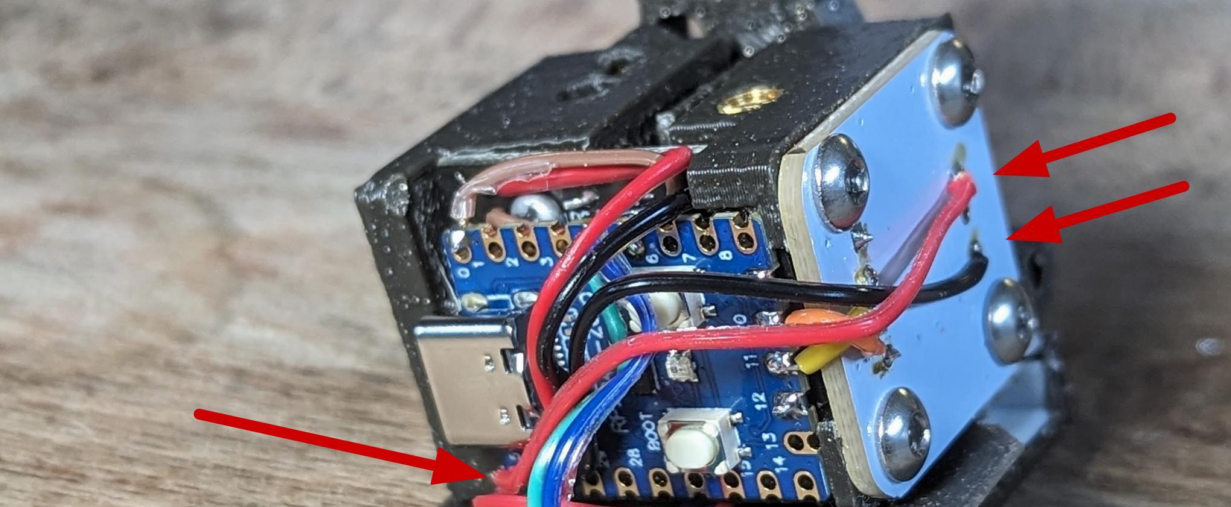
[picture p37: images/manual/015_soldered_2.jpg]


Add the female JST-XH header to `wire_cover.stl`, and solder wires to the connector. The red (5V) and black (GND) wires are soldered to the RP2040 5V and GND pads, the green and blue wires are soldered to the RP2040 GP4/GP5 pads.

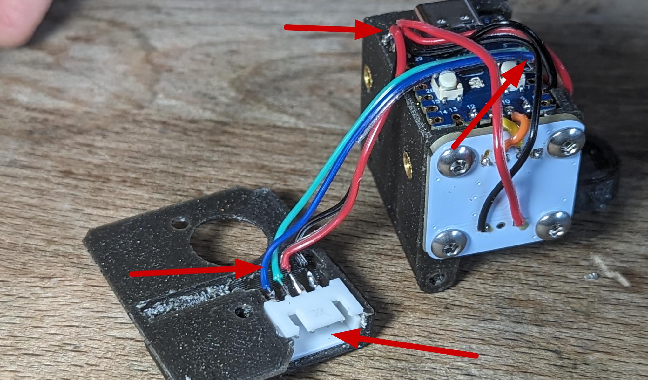
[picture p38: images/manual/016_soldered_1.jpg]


Make sure you solder on the correct pads as pictured. The numbering starts at 0 and the silkscreen alignment can be misleading.

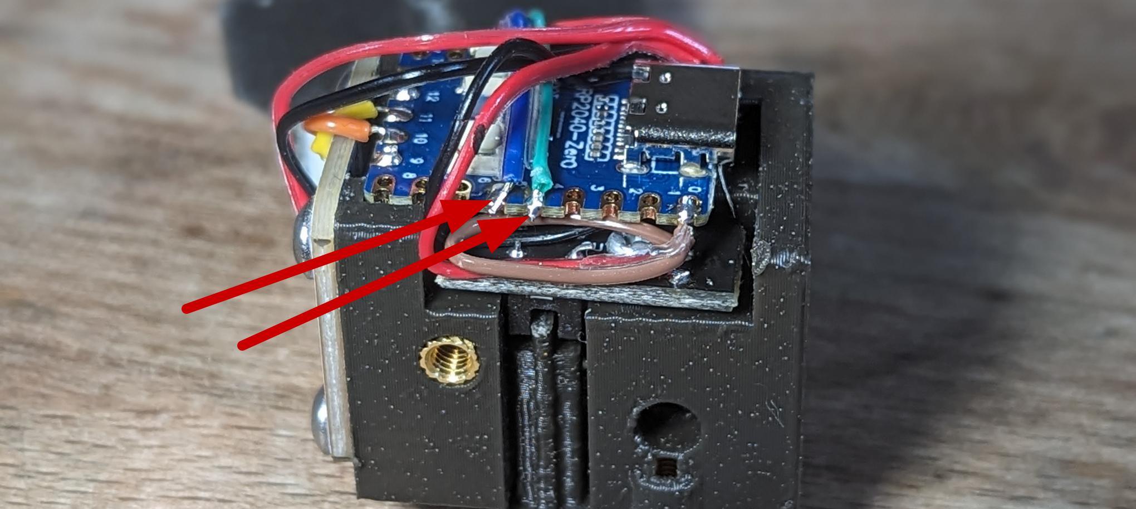
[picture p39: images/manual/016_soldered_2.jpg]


Fit the wires into the channel built into the wire cover, make sure the wires aren't getting pinched.

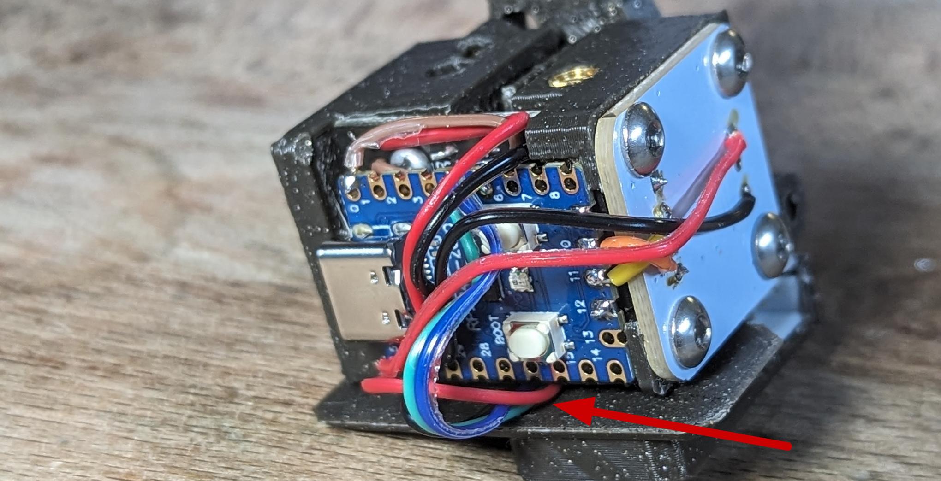
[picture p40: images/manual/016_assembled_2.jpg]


Add the M3 x 6mm BHCS and M3 x 10mm BHCS to the secure wire cover.

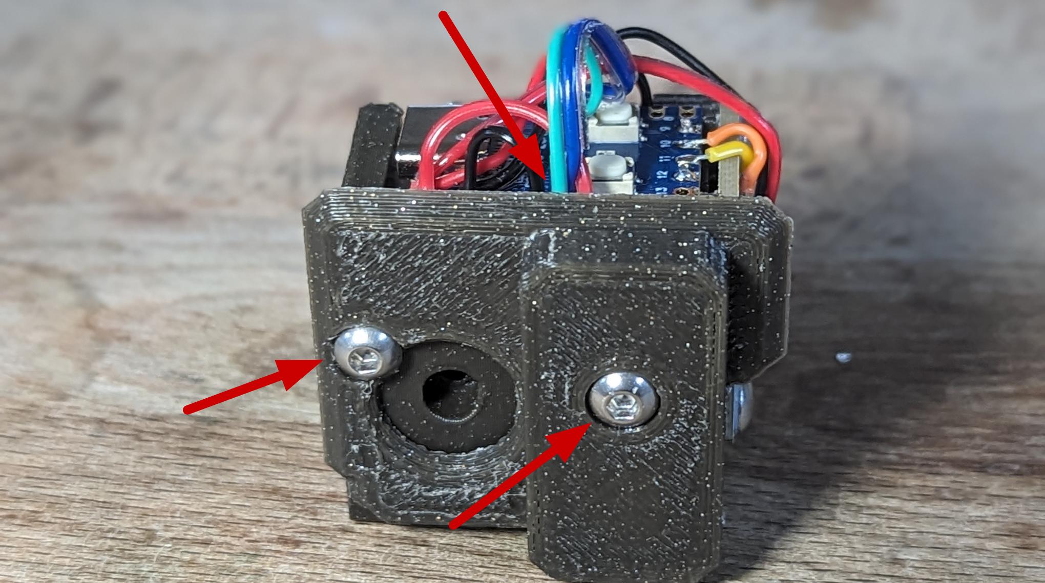
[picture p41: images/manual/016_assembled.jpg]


Push the wires neatly snug together, without covering the RP2040 buttons or the LED.

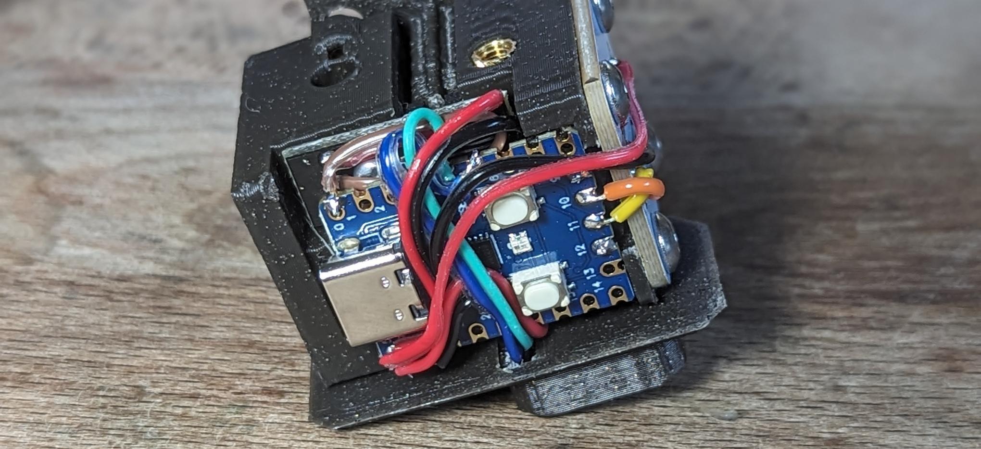
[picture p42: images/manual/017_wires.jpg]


### Flashing and testing

Now is time to flash the RP2040 and test your work!

1. Head over to the [releases](https://github.com/EiNSTeiN-/roadrunner-filament-sensor/releases) page.
2. Download the firmware for your configuration, for example `roadrunner_v1_uart_rgb.uf2`.
3. Connect RP2040 to your computer with a USB cable.
4. Press the `BOOT` and `RESET` buttons together, release the `RESET` button, and 1 second later release the `BOOT` button.
5. A drive named `RPI-RP2` will appear on your computer
6. Copy the `.uf2` file to the `RPI-RP2` drive, the RP2040 will reboot and the LED will light up.

##### Communication over USB, UART or I2C?

Serial over USB, UART and I2C firmwares are available to provide options for all MCUs and toolhead boards. There's pros and cons to both, the main ones are listed below:

**Serial over USB:**
* Pro: More convenient for some configurations (no wiring required).
* Con: Does not work when the sensor is connected to a toolhead board or the host does not have a USB port available.

**UART:**
* Pro: Good option for MCUs with limited number of pins or without native I2C support. I2C SDA/SCL pins are often special-purpose pins whereas any GPIOs can be used for UART TX/RX.
* Con: The protocol is implemented using bitbang, which is all-around less efficient compared to MCUs that have native I2C support.
* Con: It's only possible to read 4 bytes at a time over UART, so multiple reads are necessary for every update from the sensor, leading to increased communication overhead.
* Con: The implementation is more prone to errors during communication with the RP2040, leading to even greater communication overhead due to retries.

**I2C:**
* Pro: Can be daisy-chained to attach multiple sensors using only 2 pins (requires re-compiling the firmware to get unique I2C IDs).
* Pro: Can read all data from sensor in one go, which lowers the overhead between the MCU and the host.
* Pro: During testing, I2C was less prone to communication failures than UART.
* Con: I2C errors are unrecoverable. In case the RP2040 stops responding or there are delays on the i2c bus for any reason, the printer will perform an emergency stop with an `i2c timeout` error.

If you have available pins on your MCU, I2C is recommended. Otherwise use UART.

##### Flashing red LED (wiring issues)

The LED will flash red when there is an error with the AS5600 board:



Possible reasons for this state include:
1. The AS5600 is not responding over the I2C bus.
2. The magnet is too weak, too strong or not detected at all.

If you assembled the sensor correctly, the magnet should be in the correct place, so the most likely reason for this error is an issue with the wiring for the AS5600 board.

##### Solid red, green or blue LED

If everything is soldered correctly, moving the idler into and out of the IR sensor should toggle the LED between blue and green.

Troubleshooting:
1. If the LED stays the same color when the IR sensor is obstructed, the IR sensor may be soldered incorrectly.
2. If the LED switches between red and blue instead of green and blue, you may have a RP2040-Zero clone with an GRB neopixel. Simply flash the GRB firmware variant and that should fix the issue.

Once the lever arm can be actioned by hand, test with a piece of filament. Trim the lever arm slightly so inserting the filament will push the arm out of the way of the IR sensor, and removing the filament will obstruct the sensor.

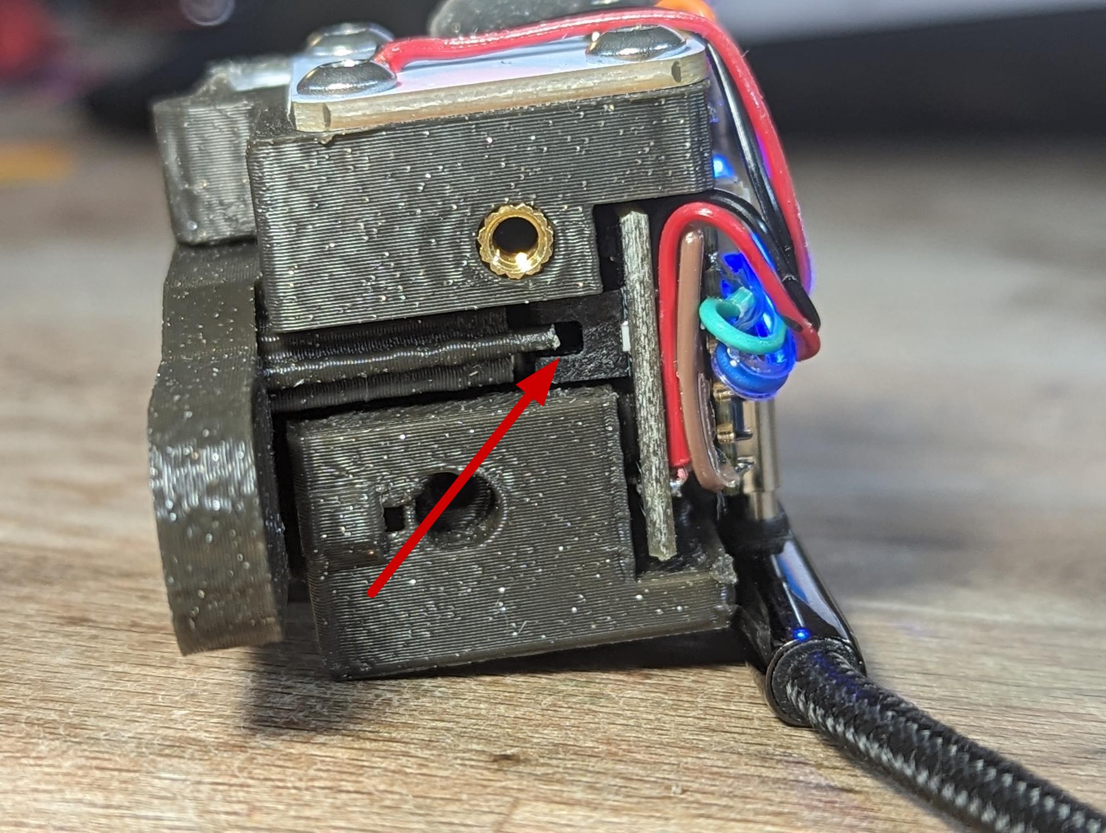
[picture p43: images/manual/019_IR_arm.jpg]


Once everything is done, your sensor should work!



### Final touches

Add the cover, printed in your favorite accent color.

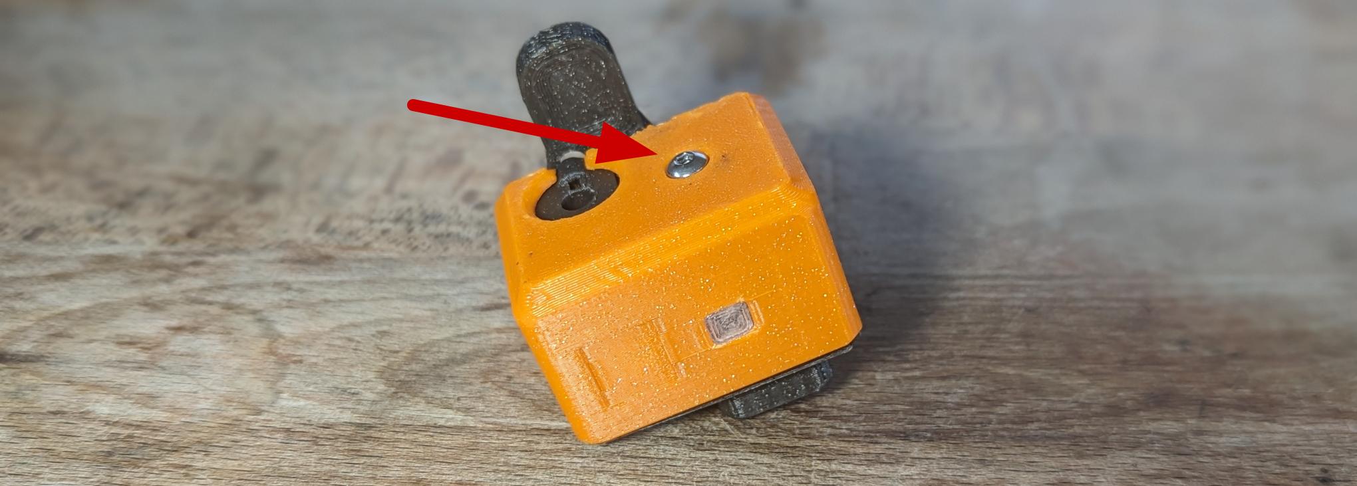
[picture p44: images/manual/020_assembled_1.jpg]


Add the PC4-M5 fittings on top and bottom.

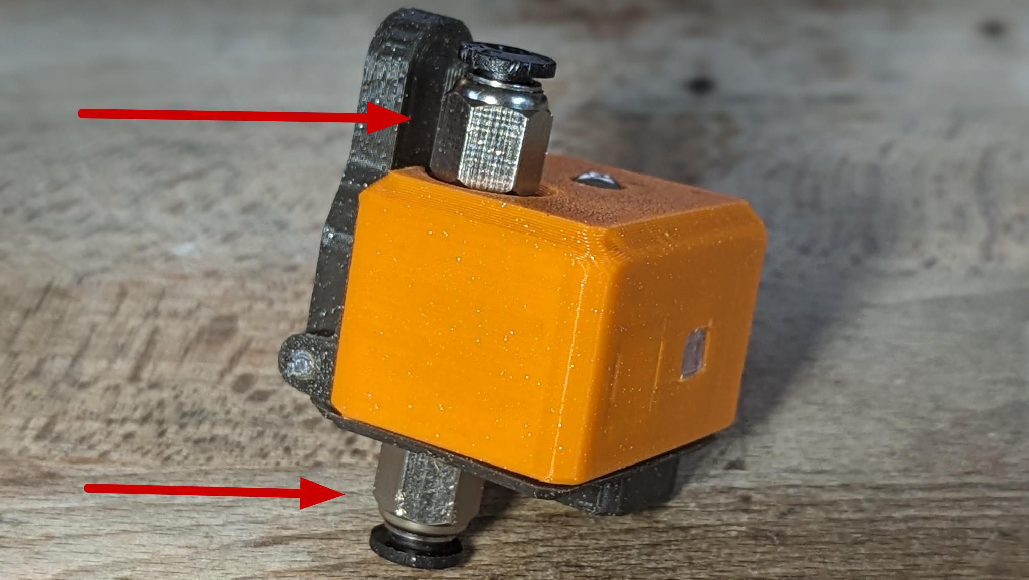
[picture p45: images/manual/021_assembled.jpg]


Lastly, add the spring assembly

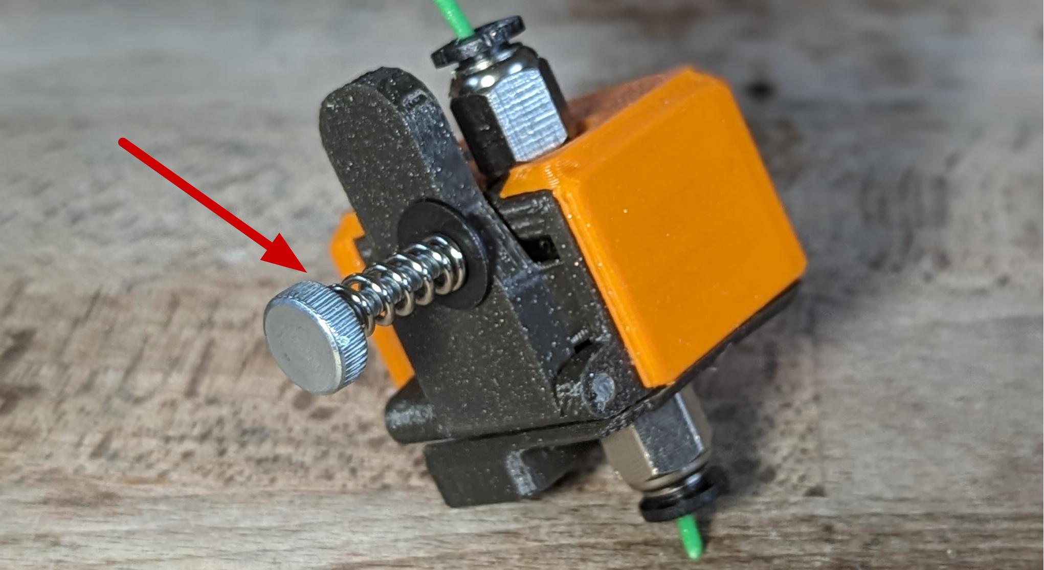
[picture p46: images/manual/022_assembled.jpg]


Your sensor is completed!

### Connect to printer

Connection to the printer is dependent on which board the sensor will be connected to. Check the [wiring manual](./WIRING.md) for information on how to connect the sensor to your toolhead board or your printer controller board.

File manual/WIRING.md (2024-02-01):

# Wiring

There are three ways to communicate with the Roadrunner sensor:
* I2C or UART connected to any MCU, or
* Serial over USB connected to the host.

Each has a respective firmware variant, and depending on which variant is flashed on the rp2040 board, you'll need to connect the Roadrunner to the printer correctly.

### UART

Any 2 GPIOs can be used for UART communication, which makes it very convenient on some boards. UART communication can be less reliable and requires more overhead, so I2C is preferred if possible. Find the schematics for the mcu your Roadrunner sensor will be connected to, and find any 4-pin (or more) connector which has `5V`, `GND` and two GPIOs available.

### I2C

Native I2C communication requires special purpose pins to be available on a microcontroller. Some boards have a dedicated connector available for I2C, but many do not.

To find out which buses are compiled into your version of klipper, download `klipper.log` and search for `BUS_PINS_i2c`. There will be one line for each MCU with all i2c buses listed by name with the corresponding pins.

Below are some of the common boards you might want to connect this sensor to.

### Serial over USB

Simply connect over USB, you can leave out the bottom wire cover.

#### BTT SB2209/SB2240 (stm32 mcu)

Schematics: [SB2209](https://github.com/bigtreetech/EBB/blob/master/EBB%20SB2240_2209%20CAN/SB2209/Hardware/SB2209.png), [SB2240](https://github.com/bigtreetech/EBB/blob/master/EBB%20SB2240_2209%20CAN/SB2240/Hardware/SB2240.png)

| Klipper bus name | Connector | SCL | SDA | Notes |
|---|---|---|---|---|
| i2c1_PB6_PB7 | Endstop | Stop1 (PB6) | Stop3 (PB7) | Less convenient since each pin is located on a different connector |
| i2c1_PB8_PB9 | BLTouch | PROBE (PB8) | SERVOS (PB9) | |
| i2c1_PA9_PA10 | SPI_OUT | IO (PA9) | NSS (PA10) | |
| i2c2_PB10_PB11 | SPI_OUT | CLK (PB10) | MOSI (PB11) | |

#### BTT SB2209 (rp2040 mcu)

Schematics: [SB2209](https://github.com/bigtreetech/EBB/blob/master/EBB%20SB2209%20CAN%20(RP2040)/Hardware/EBB%20SB2209%20CAN%20V1.0%EF%BC%88RP2040%EF%BC%89-Pin.png)

There are no good options for I2C on this board, the least bad option is to use USB-C for communication with the klipper host, which frees up the CAN-L/CAN-H pins to connect the sensor over I2C. Unless you only need one hotend fan or can relocate one fan to another pin.

| Klipper bus name | Connector | SCL | SDA | Notes |
|---|---|---|---|---|
| i2c0b | CAN port | CAN-L (gpio5) | CAN-H (gpio4) | Only usable when the board is connected via USB-C |
| i2c0d | SB0000 | Parts cooling fan (gpio13) | TACH (gpio12) | Only usable when PWM fan and parts cooling fan are not used on SB0000 |
| i2c1d | SB0000 | PWM (gpio15) | Hotend Fan (gpio14) | Only usable when PWM fan and hotend fans are not used on SB0000 |

#### BTT EBB36/42 V1.0 (stm32 mcu)

Schematics: [EBB36](https://github.com/bigtreetech/EBB/blob/master/EBB%20CAN%20V1.0%20(STM32F072)/EBB36%20CAN%20V1.0/Hardware/EBB36%20CAN%20V1.0-PIN.png), [EBB42](https://github.com/bigtreetech/EBB/blob/master/EBB%20CAN%20V1.0%20(STM32F072)/EBB42%20CAN%20V1.0/Hardware/EBB42%20CAN%20V1.0-PIN.png)

| Klipper bus name | Connector | SCL | SDA | Notes |
|---|---|---|---|---|
| i2c1_PB6_PB7 | I2C | PB6 | PB7 | Best option |
| i2c1_PB8_PB9 | CAN | RX (PB8) | TX (PB9) | Only usable when the board is connected via USB-C |

#### BTT EBB36/42 V1.1 / V1.2 (stm32 mcu)

Schematics: [EBB36](https://github.com/bigtreetech/EBB/blob/master/EBB%20CAN%20V1.1%20(STM32G0B1)/EBB36%20CAN%20V1.1/Hardware/EBB36%20CAN%20V1.1%26V1.2-PIN.png), [EBB42](https://github.com/bigtreetech/EBB/blob/master/EBB%20CAN%20V1.1%20(STM32G0B1)/EBB42%20CAN%20V1.1/Hardware/EBB42%20CAN%20V1.1%26V1.2-PIN.png)

| Klipper bus name | Connector | SCL | SDA | Notes |
|---|---|---|---|---|
| i2c3_PB3_PB4 | I2C | PB3 | PB4 | Best option |
| i2c1_PB6_PB7 | Endstop | PB6 | PB7 | |
| i2c1_PB8_PB9 | Probe | PB8 | PB9 | |

#### Mellow Fly SB2040 V2 (rp2040 mcu)

Schematics: [Fly SB2040 v2](https://www.fabreeko.com/cdn/shop/products/Mellow-Fly-SB2040-V1-Board-For-Voron-2-4-R2-Trident-Stealthburner-CW2-Extruder-Klipper-Hotend.jpg_Q90.jpg__4_550x.webp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)

| Klipper bus name | Connector | SCL | SDA | Notes |
|---|---|---|---|---|
| i2c0d | EXP | FAN0 (gpio13) | RGB (gpio12) | |
| i2c0e | EXP | PWM1 (gpio17) | PWM0 (gpio16) | |
| i2c0h | Endstop | gpio29 | gpio28 | |

#### Fystec SB CAN Toolhead Board (stm32 mcu)

Schematics: [SB CAN TH](https://wiki.fysetc.com/SB%20CAN%20ToolHead/)

| Klipper bus name | Connector | SCL | SDA | Notes |
|---|---|---|---|---|
| i2c1 | IN.0 / IO.2 | IN.0 (PB6) | IO.2 (PB7) | |

#### BTT SKR v1.1 (lpc176x mcu)

Schematics: [SKR v1.1](https://github.com/bigtreetech/BIGTREETECH-SKR-V1.1/blob/master/hardware/SKR%20V1.1%20PINOUT.pdf)

| Klipper bus name | Connector | SCL | SDA | Notes |
|---|---|---|---|---|
| i2c1 | E1 motor | STEP (P0.1) | DIR (P0.0) | |
| i2c1a | Z motor | STEP (P0.20) | EN (P0.19) | |

#### BTT SKR v1.3 (lpc176x mcu)

Schematics: [SKR v1.3](https://github.com/bigtreetech/BIGTREETECH-SKR-V1.3/blob/master/BTT%20SKR%20V1.3/hardware/SKR-V1.3-pinout.jpg)

| Klipper bus name | Connector | SCL | SDA | Notes |
|---|---|---|---|---|
| i2c1 | E1 motor | STEP (P0.1) | DIR (P0.0) | |
| i2c1a | Y motor | DIR (P0.20) | STEP (P0.19) | |

#### BTT SKR v1.4 (lpc176x mcu)

Schematics: [SKR v1.4](https://github.com/bigtreetech/BIGTREETECH-SKR-V1.3/blob/master/BTT%20SKR%20V1.4/Hardware/SKR-V1.4-pinout.jpg)

| Klipper bus name | Connector | SCL | SDA | Notes |
|---|---|---|---|---|
| i2c1 | I2C | SCL (P0.1) | SDA (P0.0) | Best option for this board |
| i2c1a | Y motor | DIR (P0.20) | STEP (P0.19) | |

#### BTT SKR 2 (stm32 mcu)

Schematics: [SKR 2](https://github.com/bigtreetech/SKR-2/blob/master/Hardware/BIGTREETECH%20SKR%202-Pin.pdf)

| Klipper bus name | Connector | SCL | SDA | Notes |
|---|---|---|---|---|
| i2c1 | Fans | FAN1 (PB6) | FAN2 (PB7) | |
| i2c1a | I2C | PB8 | PB9 | Best option for this board |
| i2c2 | Wifi | PB10 | PB11 | |

#### BTT SKR 3 / SKR 3 EZ (stm32 mcu)

Schematics: [SKR 3](https://github.com/bigtreetech/SKR-3/blob/master/Hardware%20(SKR%203)/BIGTREETECH%20SKR%203-PIN.pdf), [SKR 3 EZ](https://github.com/bigtreetech/SKR-3/blob/master/Hardware%20(SKR%203%20EZ)/BIGTREETECH%20SKR%203%20EZ%20V1.0-PIN.pdf)

| Klipper bus name | Connector | SCL | SDA | Notes |
|---|---|---|---|---|
| i2c1 | Fans | FAN1 (PB6) | FAN0 (PB7) | |
| i2c2 | Wifi | PB10 | PB11 | |

#### BTT Octopus v1.0 / Octopus Pro (stm32 mcu)

Schematics: [Octopus v1.0](https://github.com/bigtreetech/BIGTREETECH-OCTOPUS-V1.0/blob/master/Hardware/BIGTREETECH%20Octopus%20-%20PIN.pdf), [Octopus Pro](https://github.com/bigtreetech/BIGTREETECH-OCTOPUS-Pro/blob/master/Hardware/BIGTREETECH%20Octopus%20Pro%20V1.1-Pin.jpg)

| Klipper bus name | Connector | SCL | SDA | Notes |
|---|---|---|---|---|
| i2c1 | Probe | PB6 | PB7 | |
| i2c1a | I2C | PB8 | PB9 | Best option for this board |

#### Others

Finding a suitable connector on any board is relatively easy, you can follow these steps for your specific board:

1. Find the type of processor on your board, for example STM32 for the BTT SB2209, lpc1769 for the BTT SKR 1.4, etc.
2. In the [klipper repository](https://github.com/Klipper3d/klipper/tree/master/src), locate a file named `i2c.c` within the sub-folder for your processor type, for example [`src/lpc176/i2c.c`](https://github.com/Klipper3d/klipper/blob/master/src/lpc176x/i2c.c).
3. The bus name with corresponding pin names are listed in the file, for example the line `DECL_CONSTANT_STR("BUS_PINS_i2c1", "P0.1,P0.0");` means the bus named `i2c1` has its SCL and SDA pins on `P0.1` and `P0.0` respectively.
4. Find schematics for your board which has all the connectors labeled with pins.
5. With the schematics, check which of the available connectors on your board map to an I2C bus.

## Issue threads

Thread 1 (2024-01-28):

Communication between the sensor/host via USB

mainzerp, 2024-01-28:
Hi,

would i be possible to add a firmware variant to let the sensor communicate via usb?

-Schokoladenbrezel

EiNSTeiN-, 2024-01-28:
Hi! Thanks for the suggestion, I've implemented the option with https://github.com/EiNSTeiN-/roadrunner-filament-sensor/commit/0db8af00ef29fb4923cfbe672934222d15fd7dec and https://github.com/EiNSTeiN-/roadrunner-filament-sensor/commit/b78dd77db461f2e9db71afce3074a9d35e08fd71 but this new code is still untested. I'll upload the compiled firmware as soon as I can find some time to validate the new functionality.

mainzerp, 2024-01-29:
Thanks for the fast reply. If you need someone for testing, let me know.

SartorialGrunt0, 2024-01-31:
I just ordered hardware and would be willing to test as well. USB would be easier to route then I2C.

EiNSTeiN-, 2024-02-01:
I added a new commit b7330ef7bf16621f5a04c85b01e746bac25c9b6f, tested reading data with the sensor successfully and added the firmware to the 1.0 release here: https://github.com/EiNSTeiN-/roadrunner-filament-sensor/releases/tag/v1.0

EiNSTeiN-, 2024-02-01:
Thanks again for the suggestion, I'll close this one as done but let me know if there is an issue. I likely won't be running my own sensors over serial so I'm unlikely to find bugs in this part of the code.

Closed 2024-02-01.

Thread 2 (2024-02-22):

Printability Improvements

mjonuschat, 2024-02-22:
Updated CAD with:
- integrated breakaway supports for Body A
- cross bridge holes for Body B
- integrated breakaway supports for Wire Cover

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

[Filament Motion Sensor (Printability).step.zip](https://github.com/EiNSTeiN-/roadrunner-filament-sensor/files/14368875/Filament.Motion.Sensor.Printability.step.zip)

SartorialGrunt0, 2024-04-01:
This definitely needs to make its way into master. Did you want to the sequential bridging holes for the [a]_cover as well?

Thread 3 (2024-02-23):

Mounting

JamesH1978, 2024-02-23:
Good afternoon,

Do you have any tips for mounting this? I would assume it has to sit rigid inline at the extruder entrance, As I can see issues with the sensor that senses the extrusion having issues when the tool head moves a distance and pulls the reel. therefore pulling it fast through the sensor, or is this accounted for? There also does not seem to be any mounting points on the device to be able to screw it down somewhere.

Thanks for designing this, it looks like a great device and i cant wait to start using it.

James

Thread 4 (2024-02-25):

Missing walls when slicing

iJebus, 2024-02-25:
When slicing `body_part_a.stl`, I'm getting missing walls. I've tried with a few different slicers (SS, PS, Orca) and I've run into it with each. I've tried with thin walls on/off, arachne on/off, different extrusion widths; am I missing something obvious? The only way I've been able to get it to not have holes is to reorient the part per the original commit.

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

Corner is bottom left as seen here.
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

Reoriented, no missing walls.
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

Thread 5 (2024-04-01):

Add USB Support from my Fork

SartorialGrunt0, 2024-04-01:
Hello,

The current release of STL's doesn't support a USB input with a cover installed. In my fork I have added a 2020, 1515 extrusion mount, added a hole for the USB port in part [a]_cover, and modified the wire_cover.stl to remove the JST. Do you want to merge this into your main? I have tested it and everything seems to fit well, but a second tester wouldnt be bad.

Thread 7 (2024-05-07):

Multiple sensors on tool changer setup possible?

brex480, 2024-05-07:
Just wondering if running multiple sensors is possible. I see in the config it references extruder so does that mean it is possible to have one for each of my extruders? A config for each referencing the correct extruder.

testingforbugs, 2024-08-15:
yes you can have multiple sensors installed

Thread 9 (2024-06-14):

Friction

recrudesce, 2024-06-14:
Printed and built this 3 times now.  There's WAY too much friction between the gears when the arm is closed, so much so that it takes a lot of force to move the filament through and is guaranteed to cause extrusion issues.   The only way I can make the filament move smoothly is to pretty much have the arm completely loose.

What am I doing wrong here ?

recrudesce, 2024-06-14:
Closing as answered on discord :)

jflkjjlkdsajlkdsajlkjlkjdsaljdsa, 2024-12-04:
Hello, could you please post the solution here or post a link to discord. Thanks!

recrudesce, 2024-12-21:
I can't remember, but I think I just printed the parts at 101% size.

Closed 2024-06-14.

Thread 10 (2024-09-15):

Works with MMU?

Nathan22211, 2024-09-15:
From the looks of it, the BMG gears might interfere with automatic filament swaps.

Mavacer, 2025-02-15:
maybe attach a ring magnet on the BMG gear which installed in the original ERCF encoder?AS5600 can detect the magnet in quite far distance.
BTW, i cant figure out how to attach the encoder on happyhare firmware :(

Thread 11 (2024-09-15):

Why is this so small?

spikeon, 2024-09-15:
My giant fingers and ADHD ass cannot put this thing together.  Is there a remix of this that's just a little larger with more space for things to breathe and more room for the cables? I'm not putting mine on the toolhead, it's going in-between my dryer box and my printer.

yet-another-average-joe, 2024-10-08:
I had to massively rework the STEP files before everything fits. Replaced the fitings with M2.5 screws and inserts. Then a very hard time wiring it (some problems with my fingers). For now it is a sophisticated filament runout sensor on my 2.4. USB version, planning to make 2 more, I²C version.
It seems it was not designed with the Voron "PIF settings" in mind.

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

Great design. Don't let it die !

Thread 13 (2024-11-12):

Mismatched coupler dimension and part on PC4-M5 connectors

imagesurgery, 2024-11-12:
Coupler is specified as PC4-M5 in the text of the BoM, has a 4.6mm hole in the CAD body (Filament motion sensor > Sensor body > Body2) but has a PC4-M6 connector in the CAD as well.

I'm guessing this is an issue only with the part inserted in the CAD, as both the holes and the BoM seem to indicate a PC4-M5. The walls would be a little thin with an M6 connector, possibly, though I've not printed it yet.

https://github.com/EiNSTeiN-/roadrunner-filament-sensor/blame/964c20d2c45e33bc7731ea71be599f5dc0b7bed2/manual/BOM.md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

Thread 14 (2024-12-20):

Doesn't Work- defined_sensor paramter missing

recrudesce, 2024-12-20:
If I add the configuration as per the documentation I get the following error

```
Internal error during connect: __init__() missing 1 required positional argument: 'defined_sensor'

Once the underlying issue is corrected, use the "RESTART"
command to reload the config and restart the host software.
Printer is halted
```

The klippy log shows as follows:
```
Unhandled exception during connect
Traceback (most recent call last):
  File "/home/pi/klipper/klippy/klippy.py", line 279, in _connect
    self._read_config()
  File "/home/pi/klipper/klippy/klippy.py", line 214, in _read_config
    self.load_object(config, section_config.get_name(), None)
  File "/home/pi/klipper/klippy/klippy.py", line 198, in load_object
    self.objects[section] = init_func(config.getsection(section))
  File "/home/pi/klipper/klippy/extras/high_resolution_filament_sensor.py", line 988, in load_config_prefix
    return HighResolutionFilamentSensor(config)
  File "/home/pi/klipper/klippy/extras/high_resolution_filament_sensor.py", line 534, in __init__
    self.runout_helper = RunoutHelper(config, self)
  File "/home/pi/klipper/klippy/extras/high_resolution_filament_sensor.py", line 519, in __init__
    super().__init__(config)
TypeError: __init__() missing 1 required positional argument: 'defined_sensor'
```

I cannot find anything in the code that references `defined_sensor`

I am running the latest version of Kalico.

recrudesce, 2024-12-20:
OK, this requires the following changes to fix for Kalico:

Line 519 needs to be changed to
`super().__init__(config, sensor)`

so the whole `RunoutHelper` class reads as follows:
```
class RunoutHelper(filament_switch_sensor.RunoutHelper):
    def __init__(self, config, sensor):
        super().__init__(config, sensor)
        self._sensor = sensor
```

then Klipper service needs restarting

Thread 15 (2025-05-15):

New klipper version (v0.13.0-112-g82f540bb) doesn't work with the sensor

CookiezRGood, 2025-05-15:
From the looks of the klipper.log file, the sensor is using language that was updated with one of the most recent klipper updates. Extruder.move() was changed to Extruder.process_move() which makes the printer not able to turn on because it is referencing code that doesn't work anymore.

Error code in DoctorKlipper:

Traceback (most recent call last):
  File "/home/pi/klipper/klippy/klippy.py", line 164, in _connect
    cb()
  File "/home/pi/klipper/klippy/extras/high_resolution_filament_sensor.py", line 812, in _handle_ready
    self.orig_extruder_move = self.extruder.move
AttributeError: 'PrinterExtruder' object has no attribute 'move'

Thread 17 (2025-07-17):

LED color is not switched after inputting filament.

Cosik, 2025-07-17:
Hi,

I just finished assembly of road runner. I check all and seems so far is working till I input filament. In your manual it changing colour when you input filament. In my case it is not changing it. To se such behavior it should be connected to klipper?

Closed 2025-07-17.

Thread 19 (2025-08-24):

'PrinterExtruder' object has no attribute 'move'

jkwilling, 2025-08-24:
https://github.com/Klipper3d/klipper/commits/master/klippy/kinematics/extruder.py

Traceback (most recent call last):
  File "/home/jwilling/klipper/klippy/klippy.py", line 164, in _connect                                                                         cb()
  File "/home/jwilling/klipper/klippy/extras/high_resolution_filament_sensor.py", line 812, in _handle_ready
    self.orig_extruder_move = self.extruder.move
                              ^^^^^^^^^^^^^^^^^^
AttributeError: 'PrinterExtruder' object has no attribute 'move'
Transition to shutdown state: Internal error during ready callback: 'PrinterExtruder' object has no attribute 'move'
---------------------------------------------------------------------------------------
Klipper was updated on May 12..
   [extruder: Rename extruder.move() to extruder.process_move()] (https://github.com/Klipper3d/klipper/commit/f06eeb5c7aa5b297d0b6128b8cd878a35b6ea89d)
[KevinOConnor](https://github.com/Klipper3d/klipper/commits?author=KevinOConnor)
KevinOConnor committed on May 12

There was also a change in arguments  on the same day:
[toolhead: Initial support for adding extra axes to toolhead moves](https://github.com/Klipper3d/klipper/commit/bb281834b07cc5bc8c892e59bb701a9a079009b0)
[KevinOConnor](https://github.com/Klipper3d/klipper/commits?author=KevinOConnor)
KevinOConnor committed on May 12

---------------------------------------------------------
I updated line 812 to be:
self.orig_extruder_move = self.extruder.process_move

Also, to add the additional argument, I edited line 723 & 727 to have ea_index at the end:
723     def _capture_extruder_move(self, move_time, move, ea_index):
727         return self.orig_extruder_move(move_time, move, ea_index)

CookiezRGood, 2025-08-24:
I made a pull request with this like 3 months ago, and it hasn't been merged yet. I'm not sure if @EiNSTeiN- knows about it or not, but I hope they merge it eventually. For now, my printer is just referencing my forked code so that it doesn't have error messages in my updates

EiNSTeiN-, 2025-08-24:
Should be solved with #16

Closed 2025-08-24.

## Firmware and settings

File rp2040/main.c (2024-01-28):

/**
 * Copyright (c) 2020 Raspberry Pi (Trading) Ltd.
 *
 * SPDX-License-Identifier: BSD-3-Clause
 */

#include <stdio.h>
#include <stdlib.h>
#include <string.h>
#include <time.h>

#include "pico/stdlib.h"
#include "hardware/clocks.h"

#include "neopixel.h"
#include "as5600.h"
#include "ir_sensor.h"
#include "tmcuart.h"
#include "i2c_target.h"
#include "usbserial.h"

//#define IS_I2C_TARGET 1 // uncomment for i2c communication with printer
//#define USB_SERIAL_COMMS 1 // uncomment for serial over usb communication with printer

#define READ_ALL                    0x10
// #define READ_HEALTH                 0x20
#define READ_MAGNET_STATE           0x21
#define READ_FILAMENT_PRESENCE      0x22
#define READ_FULL_TURNS             0x23
#define READ_ANGLE                  0x24

#define MAGNET_STATE_UNKNOWN        0
#define MAGNET_STATE_NOT_DETECTED   1
#define MAGNET_STATE_TOO_WEAK       2
#define MAGNET_STATE_TOO_STRONG     3
#define MAGNET_STATE_DETECTED       4

// #define HEALTH_UNKNOWN                 -1
// #define HEALTH_OK                       0
// #define HEALTH_AS5600_READ_FAILED       1

#define UPDATE_INTERVAL_MS 10

struct state_t {
    // uint8_t health;

    uint8_t magnet_state;
    bool filament_present;

    int32_t full_turns; // number of times the magnet has crossed the zero point
    int32_t angle; // current angle value
} __attribute__((packed)) state;

clock_t last_update;

bool update_magnet_state()
{
    uint8_t detected, too_weak, too_strong;

    if(!as5600_get_status(&detected, &too_weak, &too_strong)) {
        state.magnet_state = MAGNET_STATE_UNKNOWN;
        return false;
    }

    if(detected) {
        if(too_weak) {
            state.magnet_state = MAGNET_STATE_TOO_WEAK;
        }
        else if(too_strong) {
            state.magnet_state = MAGNET_STATE_TOO_STRONG;
        }
        else {
            state.magnet_state = MAGNET_STATE_DETECTED;
        }
    } else {
        state.magnet_state = MAGNET_STATE_NOT_DETECTED;
    }

    return true;
}

bool update_magnet_angle()
{
    uint16_t angle;

    if(!as5600_get_angle(&angle)) {
        return false;
    }

    // check if the change is too large in either direction,
    // meaning the angle looped around across the zero position
    int32_t change = (angle - state.angle);
    if(change > 2048 || change < -2048) {
        if(state.angle > 2048) {
            // previous angle was close to max value (4096)
            // change = (angle + 4096) - state.angle;
            // e.g. state.angle=4000, angle=4, change=100
            state.full_turns += 1;
        }
        else {
            // previous angle was close to min value (0)
            // change = (angle - 4096) + state.angle;
            // e.g. state.angle=4, angle=4000, change=100
            state.full_turns -= 1;
        }
    }
    state.angle = angle;

    return true;
}

void note_last_updated_time()
{
    last_update = (clock_t) time_us_64() / 10000;
}

void update_loop()
{
    clock_t now = (clock_t) time_us_64() / 10000;
    if((now - last_update) * 1000 / CLOCKS_PER_SEC > UPDATE_INTERVAL_MS) {
        note_last_updated_time();

        state.filament_present = ir_sensor_value();

        if(!update_magnet_state()) {
            printf("Update magnet state failed...\n");
            // state.health = HEALTH_AS5600_READ_FAILED;
            return;
        }

        if(!update_magnet_angle()) {
            printf("Update angle failed...\n");
            // state.health = HEALTH_AS5600_READ_FAILED;
            return;
        }

        // state.health = HEALTH_OK;
    }
}

#define MEMCPY_REG_DATA(__buf, __data, __length) \
    { \
        __length = sizeof(__data); \
        memcpy(__buf, (uint8_t *)&__data, sizeof(__data)); \
    }

void prepare_register_data(uint8_t reg, uint8_t *buf, size_t *length)
{
    if(reg == READ_ALL) {
        MEMCPY_REG_DATA(buf, state, *length);
    // } else if(reg == READ_HEALTH) {
    //     MEMCPY_REG_DATA(buf, state.health, *length);
    } else if(reg == READ_MAGNET_STATE) {
        MEMCPY_REG_DATA(buf, state.magnet_state, *length);
    } else if(reg == READ_FILAMENT_PRESENCE) {
        MEMCPY_REG_DATA(buf, state.filament_present, *length);
    } else if(reg == READ_FULL_TURNS) {
        MEMCPY_REG_DATA(buf, state.full_turns, *length);
    } else if(reg == READ_ANGLE) {
        MEMCPY_REG_DATA(buf, state.angle, *length);
    }
}

int main() {
    stdio_init_all();

    neopixel_init();
    sleep_ms(100);
    neopixel_solid(RED);

    printf("Starting...\n");

    // state.health = HEALTH_UNKNOWN;
    state.magnet_state = MAGNET_STATE_UNKNOWN;
    state.filament_present = false;
    state.full_turns = 0;
    state.angle = 0;
    note_last_updated_time();

    as5600_init();
    ir_sensor_init();

#if defined(IS_I2C_TARGET) && IS_I2C_TARGET
    i2c_target_init();
#elif defined(USB_SERIAL_COMMS) && USB_SERIAL_COMMS
    usbserial_init();
#else
    tmcuart_init();
#endif

    sleep_ms(1000);

    uint16_t min, max, mang;
    as5600_get_zero_position(&min);
    as5600_get_max_position(&max);
    as5600_get_max_angle(&mang);
    printf("AS5600 min position: %u max position: %u, max angle: %u\n", min, max, mang);

    printf("Entering main loop...\n");
    neopixel_solid(OFF);

    while (1) {
        update_loop();

        if(state.magnet_state != MAGNET_STATE_DETECTED) {
            neopixel_blink(RED, 100);
        } else if(!state.filament_present) {
            neopixel_solid(BLUE);
        } else {
            neopixel_solid(GREEN);
        }

        neopixel_loop();

#if defined(USB_SERIAL_COMMS) && USB_SERIAL_COMMS
        usbserial_loop();
#elif !defined(IS_I2C_TARGET) || !IS_I2C_TARGET
        tmcuart_loop();
#endif
    }
}

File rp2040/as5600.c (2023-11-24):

#include <stdio.h>

#include "hardware/i2c.h"
#include "pico/binary_info.h"
#include "pico/stdlib.h"

#define ADDR _u(0x36)
#define I2C_INST i2c_get_instance(1)

#define DIR_PIN 9
#define SDA_PIN 10
#define SCL_PIN 11

#define DIR_VALUE 1

// hardware registers
#define REG_ZMCO        _u(0x00)
#define REG_ZPOS        _u(0x01)
#define REG_MPOS        _u(0x03)
#define REG_MANG        _u(0x05)
#define REG_CONF        _u(0x07)
#define REG_RAW_ANGLE   _u(0x0C)
#define REG_ANGLE       _u(0x0E)
#define REG_STATUS      _u(0x0B)
#define REG_AGC         _u(0x1A)
#define REG_MAGNITUDE   _u(0x1B)
#define REG_BURN        _u(0xFF)

/*
# PM(1:0)     1:0     Power Mode      00 = NOM, 01 = LPM1, 10 = LPM2, 11 = LPM3
# HYST(1:0)   3:2     Hysteresis      00 = OFF, 01 = 1 LSB, 10 = 2 LSBs, 11 = 3 LSBs
# OUTS(1:0)   5:4     Output Stage    00 = analog (full range from 0% to 100% between GND and VDD, 01 = analog (reduced range from 10% to 90% between GND and VDD, 10 = digital PWM
# PWMF(1:0)   7:6     PWM Frequency   00 = 115 Hz; 01 = 230 Hz; 10 = 460 Hz; 11 = 920 Hz
# SF(1:0)     9:8     Slow Filter     00 = 16x (1); 01 = 8x; 10 = 4x; 11 = 2x
# FTH(2:0)    12:10   Fast Filter Threshold   000 = slow filter only, 001 = 6 LSBs, 010 = 7 LSBs, 011 = 9 LSBs,100 = 18 LSBs, 101 = 21 LSBs, 110 = 24 LSBs, 111 = 10 LSBs
# WD          13      Watchdog        0 = OFF, 1 = ON
*/

#define BIT_POWER_MODE          0
#define BIT_HYSTERESIS          2
#define BIT_OUTPUT_STAGE        4
#define BIT_PWM_FREQENCY        6
#define BIT_SLOW_FILTER         8
#define BIT_FAST_FILTER_THRES   10
#define BIT_WATCHDOG            13
#define BIT_MAGNET_OVERFLOW     3
#define BIT_MAGNET_UNDERFLOW    4
#define BIT_MAGNET_DETECTED     5

#define MASK_BITS(n) ((1 << n) - 1)

bool as5600_read_raw(uint8_t reg, uint8_t *buf, size_t len) {
    i2c_write_blocking(I2C_INST, ADDR, &reg, 1, true);  // true to keep master control of bus
    return i2c_read_blocking(I2C_INST, ADDR, buf, len, false) == len;  // false - finished with bus
}

bool as5600_read8(uint8_t reg, uint8_t *val) {
    uint8_t raw;
    return as5600_read_raw(reg, val, 1);
}

bool as5600_read16(uint8_t reg, uint16_t *val) {
    uint16_t raw;
    if(!as5600_read_raw(reg, (uint8_t *)&raw, 2))
        return false;
    *val = ((raw & 0xff) << 8) | ((raw >> 8) & 0xff);
    return true;
}

bool as5600_write_raw(uint8_t reg, uint8_t *buf, size_t len) {
    i2c_write_blocking(I2C_INST, ADDR, &reg, 1, true);  // true to keep master control of bus
    return i2c_write_blocking(I2C_INST, ADDR, buf, len, false) == len;  // false - finished with bus
}

bool as5600_write8(uint8_t reg, uint8_t val) {
    return as5600_write_raw(reg, &val, 1);
}

bool as5600_write16(uint8_t reg, uint16_t val) {
    return as5600_write_raw(reg, (uint8_t *)&val, 2);
}

bool as5600_get_zmco(uint8_t *val)
{
    return as5600_read8(REG_ZMCO, val);
}

bool as5600_get_zero_position(uint16_t *val)
{
    return as5600_read16(REG_ZPOS, val);
}

bool as5600_set_zero_position(uint16_t val)
{
    return as5600_write16(REG_ZPOS, val& MASK_BITS(12));
}

bool as5600_get_max_position(uint16_t *val)
{
    return as5600_read16(REG_MPOS, val);
}

bool as5600_set_max_position(uint16_t val)
{
    return as5600_write16(REG_MPOS, val & MASK_BITS(12));
}

bool as5600_get_max_angle(uint16_t *val)
{
    return as5600_read16(REG_MANG, val);
}

bool as5600_set_max_angle(uint16_t val)
{
    return as5600_write16(REG_MANG, val & MASK_BITS(12));
}

bool as5600_get_config_raw(uint8_t *val, uint8_t start_bit, uint16_t mask)
{
    uint16_t conf;
    if(!as5600_read16(REG_CONF, &conf))
        return false;
    *val = (conf >> start_bit) & mask;
    return true;
}

bool as5600_set_config_raw(uint8_t val, uint8_t start_bit, uint16_t mask)
{
    uint16_t conf;
    if(!as5600_read16(REG_CONF, &conf))
        return false;
    conf &= ~(mask << start_bit);
    return as5600_write16(REG_CONF, conf | ((val & mask) << start_bit));
}

bool as5600_get_config_power_mode(uint8_t *val)
{
    return as5600_get_config_raw(val, BIT_POWER_MODE, MASK_BITS(2));
}

bool as5600_set_config_power_mode(uint8_t val)
{
    return as5600_set_config_raw(val, BIT_POWER_MODE, MASK_BITS(2));
}

bool as5600_get_config_hysteresis(uint8_t *val)
{
    return as5600_get_config_raw(val, BIT_HYSTERESIS, MASK_BITS(2));
}

bool as5600_set_config_hysteresis(uint8_t val)
{
    return as5600_set_config_raw(val, BIT_HYSTERESIS, MASK_BITS(2));
}

bool as5600_get_config_output_stage(uint8_t *val)
{
    return as5600_get_config_raw(val, BIT_OUTPUT_STAGE, MASK_BITS(2));
}

bool as5600_set_config_output_stage(uint8_t val)
{
    return as5600_set_config_raw(val, BIT_OUTPUT_STAGE, MASK_BITS(2));
}

bool as5600_get_config_pwm_frequency(uint8_t *val)
{
    return as5600_get_config_raw(val, BIT_PWM_FREQENCY, MASK_BITS(2));
}

bool as5600_set_config_pwm_frequency(uint8_t val)
{
    return as5600_set_config_raw(val, BIT_PWM_FREQENCY, MASK_BITS(2));
}

bool as5600_get_config_slow_filter(uint8_t *val)
{
    return as5600_get_config_raw(val, BIT_SLOW_FILTER, MASK_BITS(2));
}

bool as5600_set_config_slow_filter(uint8_t val)
{
    return as5600_set_config_raw(val, BIT_SLOW_FILTER, MASK_BITS(2));
}

bool as5600_get_config_fast_filter_threshold(uint8_t *val)
{
    return as5600_get_config_raw(val, BIT_FAST_FILTER_THRES, MASK_BITS(3));
}

bool as5600_set_config_fast_filter_threshold(uint8_t val)
{
    return as5600_set_config_raw(val, BIT_FAST_FILTER_THRES, MASK_BITS(3));
}

bool as5600_get_config_watchdog(uint8_t *val)
{
    return as5600_get_config_raw(val, BIT_WATCHDOG, MASK_BITS(1));
}

bool as5600_set_config_watchdog(uint8_t val)
{
    return as5600_set_config_raw(val, BIT_WATCHDOG, MASK_BITS(1));
}

bool as5600_get_raw_angle(uint16_t *val)
{
    return as5600_read16(REG_RAW_ANGLE, val);
}

bool as5600_get_angle(uint16_t *val)
{
    return as5600_read16(REG_ANGLE, val);
}

bool as5600_get_status_raw(uint8_t *val, uint8_t start_bit, uint16_t mask) {
    uint8_t status;
    if(!as5600_read8(REG_STATUS, &status))
        return false;
    *val = (status >> start_bit) & mask;
    return true;
}

bool as5600_get_status_magnet_too_strong(uint8_t *val)
{
    return as5600_get_status_raw(val, BIT_MAGNET_OVERFLOW, MASK_BITS(1));
}

bool as5600_get_status_magnet_too_weak(uint8_t *val)
{
    return as5600_get_status_raw(val, BIT_MAGNET_UNDERFLOW, MASK_BITS(1));
}

bool as5600_get_status_magnet_detected(uint8_t *val)
{
    return as5600_get_status_raw(val, BIT_MAGNET_DETECTED, MASK_BITS(1));
}

bool as5600_get_status(uint8_t *detected, uint8_t *too_weak, uint8_t *too_strong)
{
    uint8_t status;
    if(!as5600_read8(REG_STATUS, &status))
        return false;
    *detected = (status >> BIT_MAGNET_DETECTED) & MASK_BITS(1);
    *too_weak = (status >> BIT_MAGNET_UNDERFLOW) & MASK_BITS(1);
    *too_strong = (status >> BIT_MAGNET_OVERFLOW) & MASK_BITS(1);
    return true;
}

bool as5600_get_automatic_gain_control(uint8_t *val)
{
    return as5600_read8(REG_AGC, val);
}
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

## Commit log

2023-11-21 Initial version of the functional sensor
    [[a]_cover.stl, body_part_a.stl, body_part_b.stl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]
2023-11-21 Rename led diffuser
    [[c]_led_diffuser.stl]
2023-11-22 Add assembly image
2023-11-22 Add schematics and README touch ups
2023-11-24 Add native firmware working over UART
2023-11-26 Orient parts correctly
    [[a]_cover.stl, [c]_led_diffuser.stl, body_part_a.stl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]
2023-11-26 Add hardware and printed parts to BOM
2023-11-26 Add CAD
2023-11-27 Add images for assembly manual
2023-11-27 Small cosmetic and clearance touch-ups
    [[a]_cover.stl, magnet_holder.stl, wire_cover.stl]
2023-11-28 Add circuitpython prototype code
2023-11-28 Calculate cutoff over volumetric flow rather than extrusion length
2023-11-28 Add assembly instructions for main sensor body
2023-11-28 Add missing assembly step
2023-11-28 Finish writing assembly manual
2023-11-28 Add uart vs i2c pros and cons
2023-11-29 Improve BOM
2023-11-29 Fix BOM typo
2023-11-29 Tweak wording for assembly manual
2023-11-29 Add I2C pins on schematics
2023-11-29 Fix image orderding in assembly manual
2023-11-29 Fix another typo in the assembly manual
2023-11-29 Implement I2C target mode for communication between the sensor/host
2023-11-29 Add missing include for I2C target
    [main.c]
2023-11-29 Update klippy code for i2c support
2023-12-07 Add wiring information for UART and I2C for some boards
2023-12-08 Fix EBB36/42 I2C mapping
2023-12-08 Revert "Fix EBB36/42 I2C mapping"
    This reverts commit 4bae400506fd786c917fc13d74b76caa20873cce.
2023-12-08 Fix stm32 i2c bus names for EBB36/42
2023-12-08 Add correct bus names and one missing i2c bus for SB2209/SB2240
2023-12-08 Remove last_eventtime to reduce noise, reduce update time to 100ms
    [high_resolution_filament_sensor.py]
2023-12-12 Fix detection for end of runout condition, minor whitespace fixes
    [high_resolution_filament_sensor.py]
2023-12-19 Add some typing annotations, add more docstrings, keep track of commanded extruder position as well as the expected and measured positions
2023-12-19 Add small script to debug live data from sensor
2023-12-22 Improve motion tracking, improve error handling for gcode commands, simplify gcode commands using the new motion tracking code
    [high_resolution_filament_sensor.py]
2023-12-27 Add handling around edge cases where extruder is not moving
2023-12-29 Fix schematics and assembly manual to indicate AS5600 is powered from 3v in the normal configuration
2024-01-04 Move the calibration gcode macros into their own file, and improve calibration runs wiht a least-square curve fitness test to detect bad collected data
2024-01-05 Improve how we keep track of extruder position for each CommandedMove, and some improvements to the flow calibration macro
2024-01-09 Use absolute angular position from sensor to avoid errors introduced by floating point maths
    [high_resolution_filament_sensor.py]
2024-01-16 Configurable number of hysteresis bits, simplify rotation helper and distance calculation code, make sure the code works with negative distances. Improve corrected rotation_distance calculation.
    [high_resolution_filament_sensor.py, high_resolution_filament_sensor_calibration.py]
2024-01-17 Improve max flow macro with better statistical model. Add ability to produce a graph of all collected values on demand. Add new details to README for better results
2024-01-17 Small improvements to max flow macro
2024-01-18 Implement experimental non-linear extrusion compensation macro
2024-01-18 Implement FILAMENT_SENSOR_MEASURE command for debugging, and improve suggestion in max flow calibration
2024-01-18 Add max flow suggestions to the graph
2024-01-19 Make sure toolhead max velocity is taken into account before non-linear compensation is applied
2024-01-22 Disable updates from filament sensor during homing. Also some minor fixes
    [high_resolution_filament_sensor.py, high_resolution_filament_sensor_calibration.py]
2024-01-28 Move non-linear extrusion compensation to its own file
2024-01-28 Remove i2c_timeout from config example in README
2024-01-29 Handle edge case when no movements are available
2024-01-30 Add virtual pin for compatibility with [filament_motion_sensor] and [filament_switch_sensor] klipper configuration objects
2024-01-30 Use load_object instead of lookup_object for buttons
2024-02-01 Trigger switch callbacks on first filament detection to ensure correct state after startup
    [high_resolution_filament_sensor.py]
2024-02-02 Hook extruder.move() to get a better understanding of what the printer is being commanded to do in the future
2024-04-29 Update high_resolution_filament_sensor_calibration.py
    Fix exception when calling _compute_max_flow_result
    [high_resolution_filament_sensor_calibration.py]
2025-05-18 Update high_resolution_filament_sensor.py to new klipper v0.13 syntax
    In one of the recent klipper updates, extruder.move was changed to extruder.process_move. This broke the code for the filament sensor and didn't allow the printer to turn on. Updating the places in the code with extruder.move to extruder.process_move fixed this issue. Further issues were caused by _capture_extruder_move now requiring 4 inputs rather than 3. I added "ea_index" to the inputs and the return for that section in the code so it matches that in the toolhead.py code in klipper.
    [high_resolution_filament_sensor.py]
